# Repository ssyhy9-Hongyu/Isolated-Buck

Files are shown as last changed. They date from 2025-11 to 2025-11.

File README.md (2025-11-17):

# Isolated-Buck
50W Isolated Buck Converter (Two Switch Foward Converter) Project

Project Date: Sept.2022 - Jan.2023
Location: Nottingham UK  
People: Hongyu Yan, Pengyuan Shu, Jasleen Kaur, Jed Gawan

System block diagram:


Photo of the converter:


PCB Design Schematic (Converter Board):


PCB Design Schematic (Control Board):


PCB Layout (Converter Board):


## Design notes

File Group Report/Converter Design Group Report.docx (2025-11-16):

Converter Design Group Report

Introduction

The main aim for the project is to design a fully controlled two forward converters that outputs and regulated voltage. In Figure 1, we see a 230V, 50Hz AC supply, replicating a mains supply. This is stepped down to 30V, 50Hz using a XFMR gate drive transformer. This report covers the development of two main sections, the isolated two switch forward converter and the MOSFET gate drive.

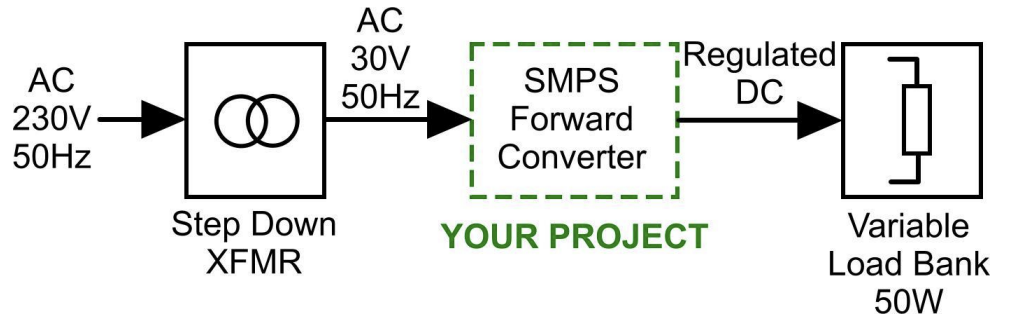
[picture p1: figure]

Figure 1. Project block diagram

The task is to produce a stable regulated output voltage across this load bank, regardless of the load. An isolated two switch forward converter is a type of converter that changes the AC input to a DC output. This converter can provide isolated output voltage. This would end up being connects to a 50W variable load bank.

The forward converter was designed and simulated under ideal and non-ideal conditions. Calculating the different components of the forward converter

Control circuits have low voltage and power levels, whilst power MOSFETs have high voltages and powers. Providing electrical isolation between these sections is mandatory to ensure safe and reliable operation. For this, the MOSFET Gate Drive circuit is responsible. Within this report, the operation of the gate drive is explored along with the purpose of each component. The need for coupling capacitors, Zener diodes and several resistors is investigated along with the effect of each component on the signal and the converter. The resultant output is then seen.

This report presents the design and simulation of a forward converter, under both ideal and non-ideal conditions. The initial calculations involved determining the necessary component values, duty cycle, and switching frequency, which in turn allowed for the calculation of important factors such as the turn ratio, output inductors, and capacitors. Non-ideal factors, including the capacitors' Equivalent Series Resistance (ESR), winding numbers, and equivalent resistance, were also taken into account. The simulations of the converter were carried out under ideal and non-ideal conditions, and the effect of an AC-derived input was also explored. The report then delves into the MOSFET Gate Drive circuit, which is crucial for providing electrical isolation between the control circuits (with low voltage and power levels) and the power MOSFETs (with high voltages and powers). The operation of the gate drive and the role of each component, such as coupling capacitors, Zener diodes, and resistors, are explored, along with their effects on the signal and the converter. The report concludes with the resultant output.

Calculations for the Forward Converter

Given values:

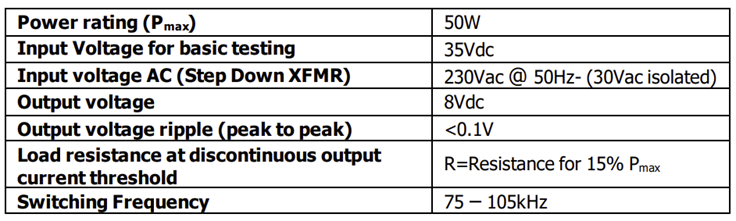
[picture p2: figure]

Duty cycle:

For the converter design, the duty cycle was limited to 50% to avoid saturation of the transformer core. Thus, initially, a duty cycle of 40% was chosen. However, a 30% duty cycle provides a higher range of the duty cycle to control the output voltage.

Turns ratio:

V_0 =((N_1)/(N_2))dV_s

(N_2)/(N_1)=(V_0)/(d∙V_s)=(8V)/(0.3∙35V)=16/21

Switching Frequency:

States anything between 75kHz and 105kHz. Decided on 100kHz.

Output filter inductor:

Use minimum load condition to get ΔI_L :

I_(RMS) =P/V=(50W×0.15)/(8V)=0.9375A

ΔI_L =I_(peak) =√3I_(RMS) =1.6238A

Voltage time area equation to find the inductance:

L=(VTA)/(ΔI_L)=(VTA)/(I_(peak))=(V_0 (1-d)∙T_(sw))/(I_(peak))=(8V∙0.7∙1/100kHz)/(1.6238A)=34.487μH

Output filter capacitor:

Use current time area equation to find the capacitance:

C_0 =(ITA)/(ΔV_0)=(I_(RMS) ∙(T_(sw))/2∙1/2)/(ΔV_0)=(0.9375A∙5μs∙0.5)/(0.1V)=23.4375μF

****************************

In terms of simulation with non-ideal components, the ESR (equivalent serial resistance) of capacitors, the DCR (DC resistance) of inductors, the resistance and forward bias voltage of diodes, the on-resistance of MOSFET, and the losses on the transformer should all be reflected on the schematic. Among all the component values, most could be found on the datasheet of their own, including the forward bias voltage of diodes, on-resistance of MOSFET etc. The following part of this section presents the methods to calculate or estimate the equivalent component values which could not be found on the datasheet directly.

Capacitor ESR Calculation:

The capacitor ESR is dependent to the capacitance and the power dissipation factor which could be found in the datasheet.

The primary part of the converter is operating around 35V and the voltage across output filter is around 10V. Therefore, the dissipation factor chosen for the corresponding capacitors are 0.12 and 0.2. The ESR could be calculated using the equation below:

ESR=tanσ∙ Xc=tanσ∙1/(2πfC)

The capacitors placed after the rectifier for smoothing the input voltage works at 100Hz while the capacitors at the output end of the converter are operating at 100kHz, the capacitances could hence be derived:

C_(output) =0.2×1/(2×π×100k×23.4375μ)=0.014Ω

C_(input) =0.12×1/(2×π×120×1000μ)=0.16Ω

Main Converter transformer winding number calculation

The number of turns on the transformer is determined by the equation below (the derivation steps are skipped):

N=(VTA)/(ΔBA_(core))

In this equation, the cross-section area of the core is settled (97.1 mm^2 ) and VTA is calculated in the worst case scenario, which refers 50% duty cycle. Although the flux density of N87 material saturates at around 500mT from the datasheet, the value of maximum flux density is chosen as 150mT to reduce the losses in the transformer and increase the efficiency. Therefore, the number of windings on the primary part of the transformer:

N=(0.5×35×1/(100k))/(150×10^(-3) ×97.1×10^(-6))=12

According to the primary and secondary turns ratio:

N_2 =N_1 ×16/21=10

The magnetising inductance of the transformer could hence be calculated using the number of turns by the equation below:

L_(mag) =A_L N^2

Where A_L =2600nH , N=12 :

L_(mag) =2600n×12^2 =374μH

The magnitude of magnetising current could be calculated based on L_(mag) to further validate of the choice of maximum flux density is reasonable or not. When the MOSFETs are at their ‘off state’, at the primary part of the converter, the magnetising current is flowing back to the power source:

I_(mag) =(VTA)/(L_(mag))=(70%×(-35)×1/(100k))/(374μ)=0.65A

It could be observed that the magnitude of the magnetising current is reasonable. Therefore, the numbers of turns on the transformer are settled as 12 turns and 10 turns.

Main Converter Transformer Winding Equivalent Resistance

The equivalent resistance of the windings is dependent on the length and the type of the copper wire which have been used to build the transformer. To choose the wire with correct diameter, the skin depth of the wire is found using the equation below:

δ=√(ρ/(πfμ_r μ_0))

The following parameters are fixed for copper material:

ρ=1.678×10^(-8) Ωm, f=100kHz, μ_r =0.99, μ_0 =4π×10^(-7)

Therefore, the skin depth is found to be 0.206mm at 100kHz for copper.

For the main converter transformer, any current density between 2-8A/mm^2 is considered reasonable and the current through the transformer is also dependent on the resistance of the load. Thus, for safety reason, the thickest wire (20AWG) is chosen which has an effective cross-sectional area of 0.39 mm^2 (after considering skin depth).

The equivalent resistance of the windings on the transformer could hence be calculated as the type of the wire and the number of turns has been chosen. The following calculations show the method to estimate the resistance:

R_(primary) =N_1 πD∙R_(wire) =0.015Ω

R_(secondary=) N_2 πD∙R_(wire) =0.012Ω

Winding Number of the Output Filter Inductor

As the inductance was calculated to be 34.57μH , the winding number of the inductor could be given as the following equation:

N=√((gL)/(μ_0 A_(core)))=√((0.5mm×34.57μH)/(4π×10^(-7) H∙m^(-1) ×97.1mm^2))=11.9

Thus, we pick N=12 as the winding number of inductor.

Inductor DC Resistance

The wire of 0.81mm diameter has been chosen for winding. The resistance of the winding could be given to be:

R_L =ρ_(cu) (L_(cu))/(A_(cu))=ρ_(cu) ×(2Nπr_(core))/(πr_(wire) ^2)=1.72×10^(-8) Ωm×(24∙5.56mm)/((0.405mm)^2)=0.014Ω

Simulations Results under ideal conditions

Simulation Settings

The simulation time was set to 0.005s and the max step size was set to 1×10^(-6) to ensure the accuracy of the simulation result. Two loads with different resistances were connected to a switch at the output end of the circuit. The step-input-driven switch would jump to the load with higher resistance from the load with lower resistance at 0.002s to simulate the change of load in real working conditions.

Results & Observations

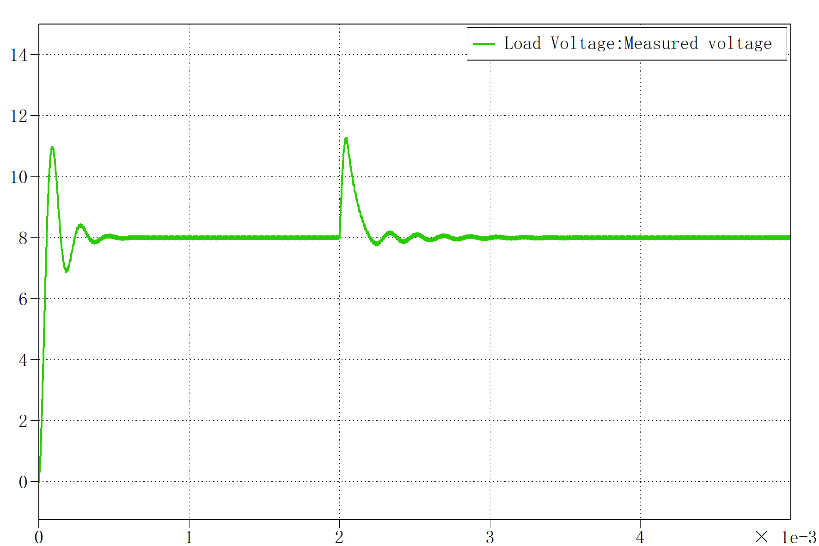
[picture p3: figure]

Figure 2. Simulation result of ideal conditions

It can be observed that there are generally two significant overshoots in the plot, where t=0s and t=2ms respectively. The output load is 2Ω initially, and has been changed to 8Ω after 2ms. It is apparent that the change of load causes the overshoot. Comparing these two overshoots, the first one takes less time than the second one to steady, this might because

Simulation results with non-ideal components

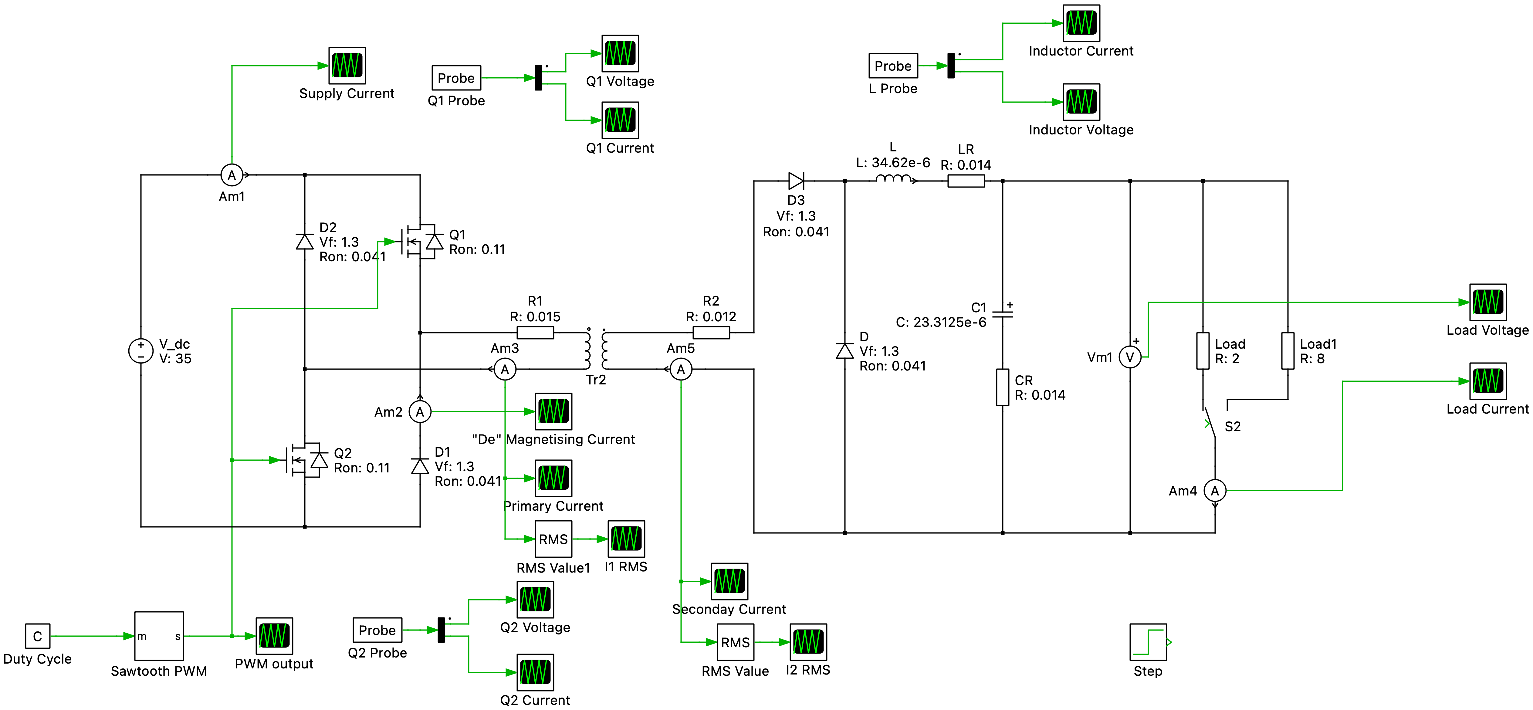
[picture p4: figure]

Figure1.1 Non-ideal Schematic With 35Vdc Input

Simulation Settings

The simulation settings of the non-ideal circuit were identical to the ideal circuit except the changes in component values as shown in the schematic above.

Results & Observations

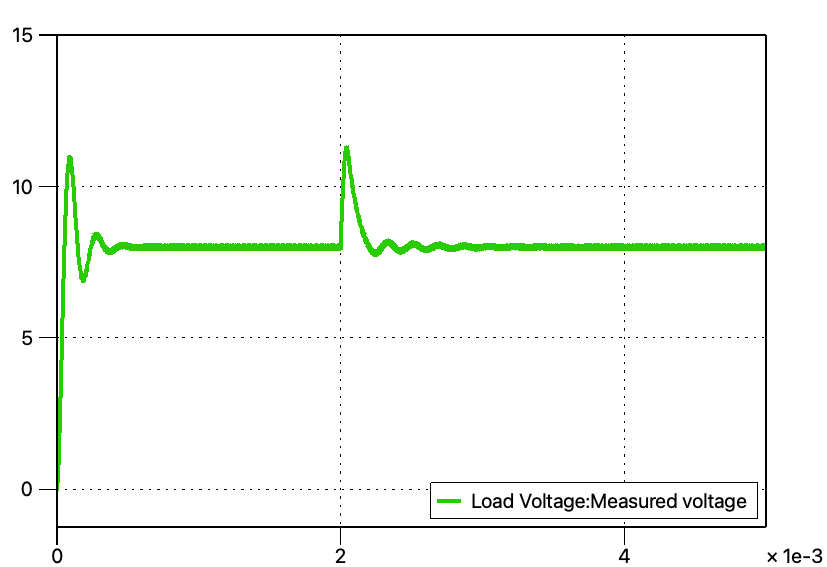
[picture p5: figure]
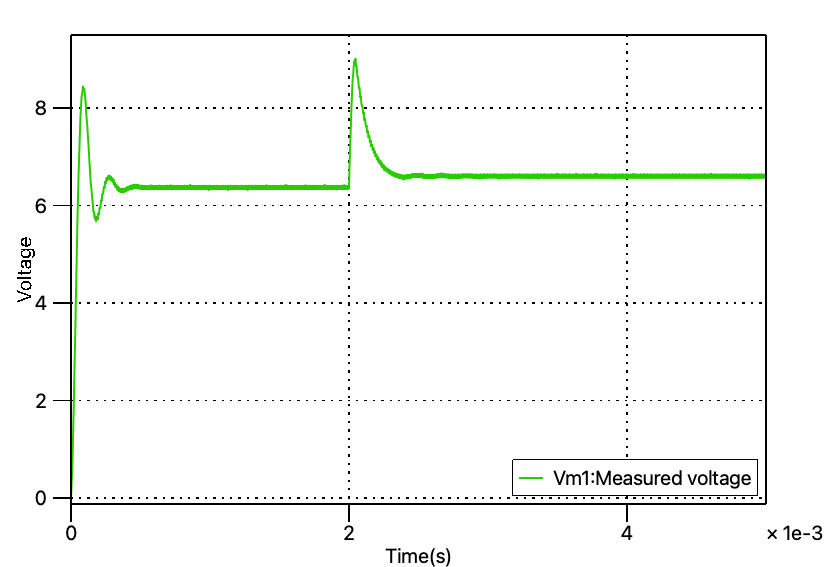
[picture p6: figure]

Figure1.2 Ideal(left) and Non-ideal(right) Output Voltage

Two major differences could be found by comparing the output voltage plot of ideal and non-ideal simulations. The first point is that the stable voltage on the load of non-ideal simulation is smaller than that of the ideal simulation. The second point is that in non-ideal simulation, the steady state voltage across a larger resistance load is higher than the voltage across a smaller resistance load.

The possible explanation to the first difference is that after taken the forward bias voltage on the diodes and the equivalent serial resistances into consideration, there would be voltage drops on every circuit component while the input voltage remains the same, which results in a relatively lower output voltage in the non-ideal simulation. In terms of the second difference, the changes in the voltage level are seemed caused by the difference in the load resistance, however, it is the difference in current which directly leads to the result. The larger load resistance would lead to a smaller current in both primary part and the secondary part of the converter. As the power rating of the converter and the turns ration on the transformer are consistent, the voltage drop across the components would hence be smaller when the current flowing in the circuit became smaller, thus, the steady state voltage across the load would be higher when a larger resistance load is applied to the circuit.

The peak to peak value of the ripples at the steady state voltage is around 0.08V, smaller than 0.1V that required by the customer. The ripples in the steady state voltage are mainly caused by the charging and de-charging process of the capacitor, therefore, the peak to peak value could be further reduced by using a capacitor with larger capacitance in the circuit. However, the feasibility of using a very large capacitor on the PCB is doubtful mainly due to the limited space on the board.

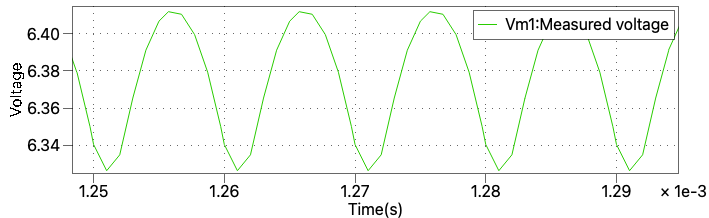
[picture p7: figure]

Figure1.3 Ripples at Steady State Voltage

Besides the observations on the output end of the converter, another simulation result that could guide the future practice is the current magnitude on the transformer. The RMS value of the current directly determines the heat losses of the converter while the current value has an inverse linear relationship with the load resistance, it is important to keep the current density on the wires at a safety region. In the case of copper wires, this figure should be around or below 5A per square millimeter according to the instructions while the thickest wire in the lab only has a cross sectional area of 0.39 mm^2 after considering the skin depth which has been calculated previously. The figures below are the RMS current values on the secondary winding under a small load(2 Ω ) and a large load(8 Ω ).

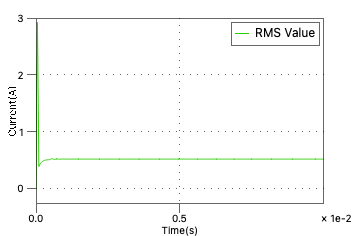
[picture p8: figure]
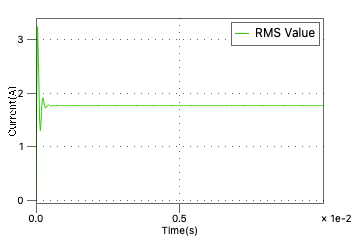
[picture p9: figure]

Figure1.4 RMS Current Value on Secondary Winding under 8 Ω (left) and 2 Ω (right) Load

The current value is roughly at 0.5A under big load and 1.8A under small load, which give an instructional idea on wire type selection in practice.

Simulation Results with AC derived input

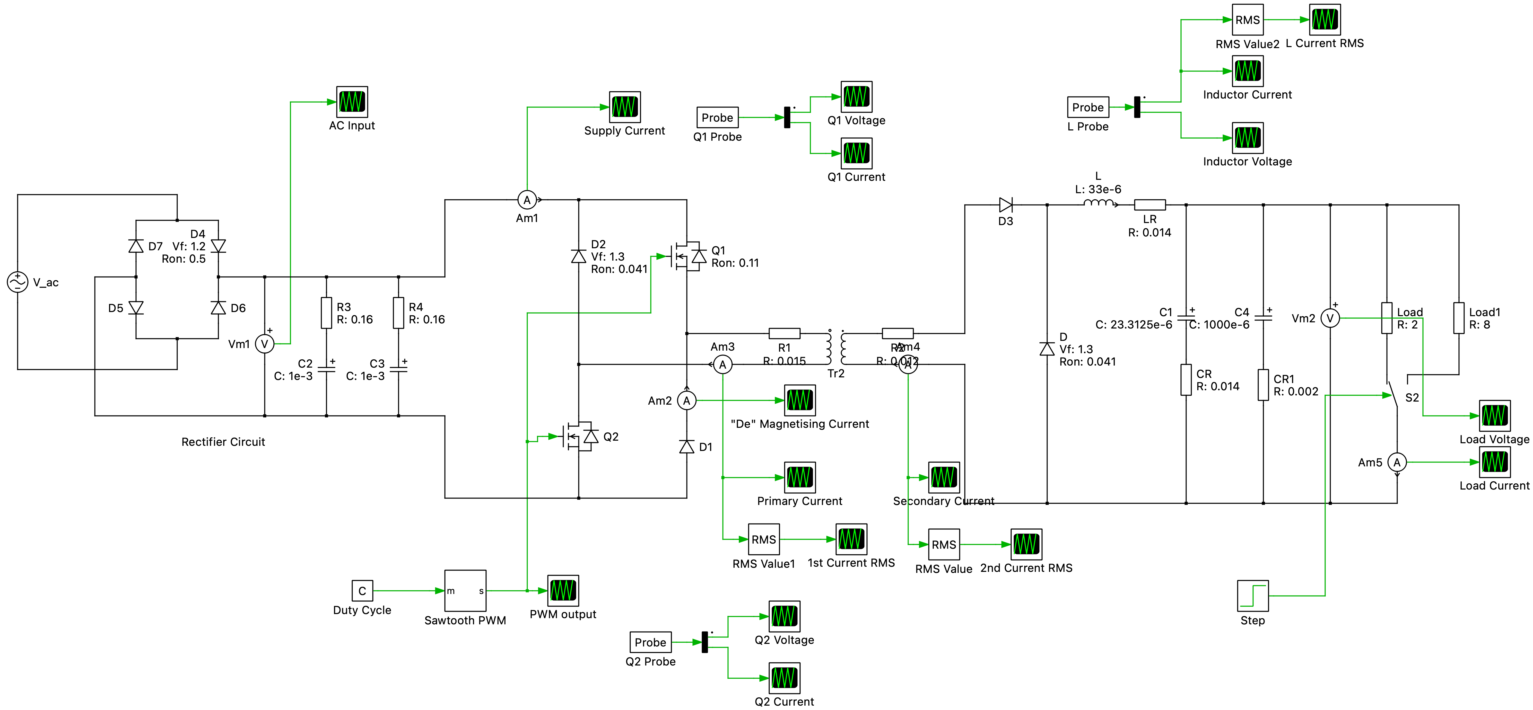
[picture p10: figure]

Figure2.1 Non-ideal Schematic with AC Input

Simulation Settings

The simulation time was increased to 0.2s to obtain the stable wave forms, the rest of settings were identical to the non-ideal circuit except the changes in circuit layout and component values as shown in the schematic above.

Results & Observations

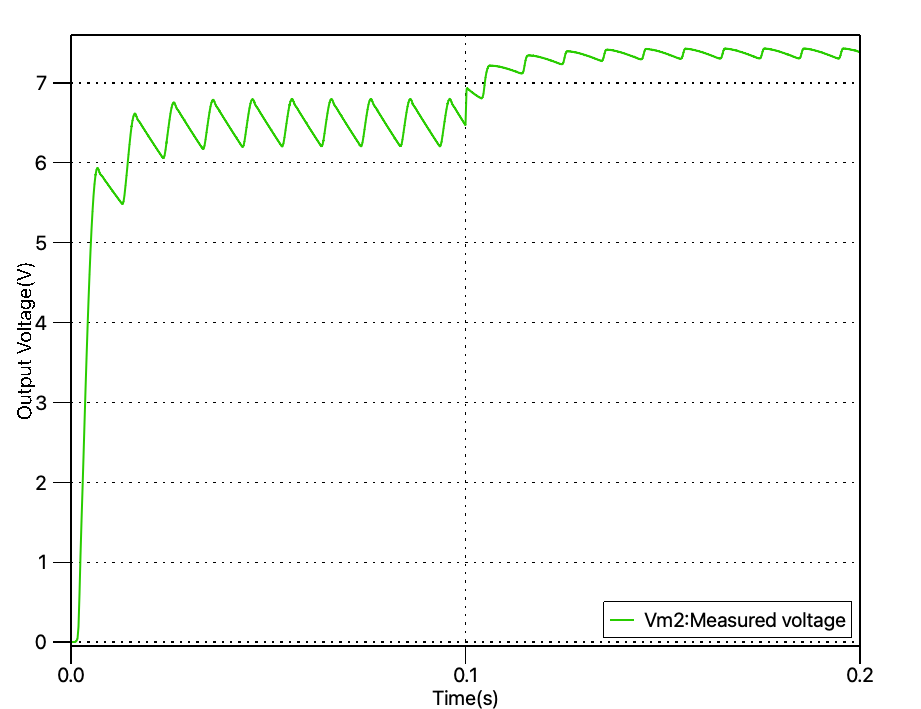
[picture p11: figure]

Figure3.1 Non-Ideal(left) and Non-Ideal with AC Input(right) Output Voltage

It is observed from the figure above that the ripples in the output voltage(not referring to the big ripples caused by the AC input) is around 0.005V, significant smaller than that in the non-ideal simulation. This change is due to a relatively large capacitor ‘CR1’added into the circuit. The capacitor

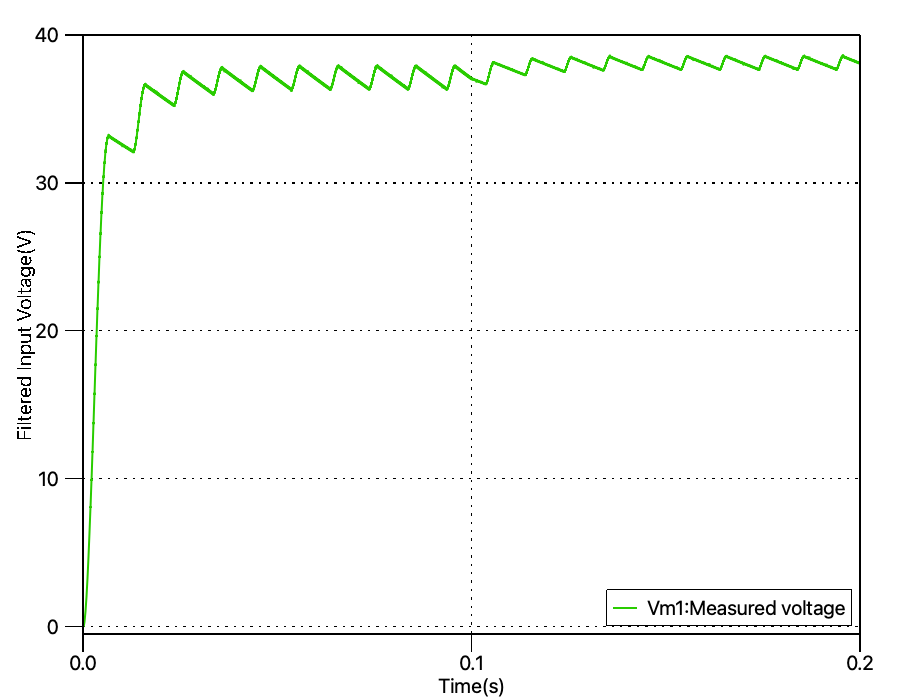
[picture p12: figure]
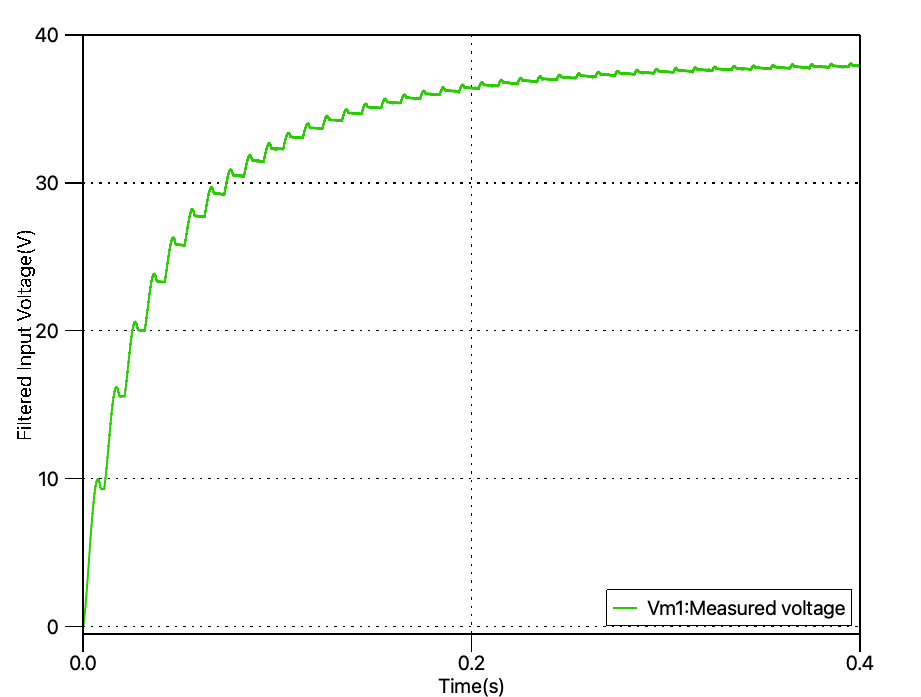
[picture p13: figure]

Figure3.2 Filter AC Input via 2uF Capacitor(left) and 20uF Capacitor(right)

Large Ripple

Small Ripple(why smaller, resistor impact)

Gate Drive Circuit

The gate driver circuit was implemented in order to provide electrical isolation between the control section of the converter and the high frequency power section. This isolation was necessary to provide safety between the high and low power components and to ensure reliable operation of the power electronics.

Figure X shows the schematic diagram of the gate driver circuit, with the MOSFETs represented as capacitors. The components within the gate driver circuit are carefully selected and arranged to enable efficient operation of the MOSFETs, which act as power switches in the converter.

In the following section, the operation of the gate driver circuit is explained in detail, with each component's purpose discussed. The selection and arrangement of components are critical for the proper functioning of the circuit, and a thorough understanding of the circuit operation is necessary for successful implementation.

Figure x: Schematic of the Gate Driver Circuit

In the gate driver circuit, the input signal was a square wave with a selected switching frequency of 100 kHz and a peak voltage of 15V. The MOSFETs, used as a power switch, required an input voltage between 12V and 15V, in accordance with its specifications. The input signal contained both AC and DC components, which necessitated the use of a coupling capacitor, C1, to block the DC components prevent the transformer from being saturated by it. If the capacitor was not used, there would be a duty cycle-dependent voltage across the transformer windings, which would cause signal distortion and potentially cause damage to the transformer. As a result of C1, a shift in the signal was caused with not peaks of approximately 10.5V and -4.5V. The capacitor value had to be kept relatively large to enable effective DC blocking and prevent signal distortion caused by the voltage drop at the capacitor.

The signal then enters a unity transformer, which provides galvanic isolation and protection between the control and power sections of the converter. The transformer in the gate drive circuit helps to ensure reliable and safe operation of high-power switching devices by allowing a safe signal transfer. To avoid time delays that can decrease system performance and reliability, such as increased power dissipation, reduced switching speed, and accuracy, a low leakage inductance is required for the transformer. Trifilar winding was used to reduce the leakage inductance. Trifilar winding involves winding wires closely together with the same number of turns, which reduced the amount of flux leakage between the windings, thus reducing the leakage inductance.

The role of the second coupling capacitor in the gate drive circuit was to restore the voltage drop within the signal, maintaining voltage levels of 15V and 0V. Meanwhile, the Zener diode functioned to clamp the voltage at a safe level, providing the MOSFET with protection from overloaded conditions. During turn-on and turn-off, the voltage levels could rise above the MOSFET's voltage rating of 20V, potentially damaging the device. However, this risk was mitigated through the use of a Zener diode with a breakdown voltage of 18V. Although the MOSFET had a maximum gate-source voltage of 20V, a voltage of 18V was used to provide an additional safety margin, especially since the MOSFET only required 12V-15V to operate.

The MOSFETs was represented with capacitors, C5 and C6, because the gate terminal of a MOSFET behaves like a capacitor, and it has to be charged and discharged through a resistor in order to turn the MOSFET on and off. The gate capacitance is typically much larger than other capacitances in the circuit, which is why it is represented separately as a capacitor. By representing the MOSFET as a capacitor, the simulation program can accurately model the charging and discharging of the gate capacitance and provide accurate results for the circuit's behaviour.

The gate resistor, RG, was responsible for charging and discharging the gate capacitance within the MOSFET which meant choosing a correct value for it was mandatory. Since, a small value of the gate resistor, caused the gate capacitor to charge faster increasing the turn on speed and thus decreasing the power losses. However, it can cause excessive current to flow into the gate at turn on, which can potentially damage the MOSFET. Thus, a suitable value limiting the current but providing a fast enough rise time was selected.

The gate source resistor, RGS, was a necessary component responsible for removing the charge stored by the parasitic capacitances, C5 and C6, between the gate and the source. Without this resistor, the MOSFET becomes unpredictable and may have floating voltages due to parasitic interference and noise. Since it was responsible for the removal of charge, its value was dependent on the time constant, which meant that a large RGS would increase the switching times leading to higher power dissipations and thus thermal losses.

From a selection of the correct components the following result was produced within figure x. It displays a peak at 14.3V and -0.7V approximately. With the voltage drops in the peaks caused by the Zener diode in forward mode.

Figure x: Output of the capacitors representing the MOSFETs

Conclusion

For gate drive: In conclusion, the gate driver circuit plays a critical role in the proper functioning of the MOSFETs. The circuit components were carefully selected and arranged to enable efficient operation of the MOSFETs. The use of coupling capacitors, a unity transformer, and Zener diodes provide reliable and safe operation of high-power switching devices, while the proper selection of gate resistors and gate-source resistors aids in reducing power losses, limiting current flow into the gate, and removing charge stored by the parasitic capacitance.

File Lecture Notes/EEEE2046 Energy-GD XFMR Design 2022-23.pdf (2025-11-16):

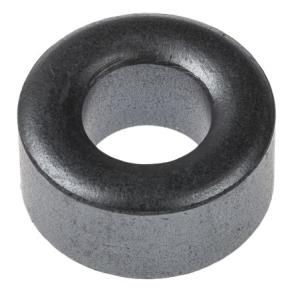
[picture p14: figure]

EE2046 Energy Project – Gate Drive Transformer Design

## Department of Electrical and Electronic Engineering

## EEEE2046 Energy: Things to consider for the Gate Drive Transformer 22-23

### 1.0 Introduction

This document provides some basic information which should be considered when designing and constructing the transformer for the MOSFET gate drives of the two transistor Forward Converter in EEEE2046 (Energy Project). It is not a complete guide for the design of the transformers but instead should be used as a reference for the most important considerations.

Figure 1: Toroidal magnetic core

The gate drive transformer should be small as it only transfers a few Watts of power from the supply to the MOSFETS. As a result a toroidal core is chosen.

### 2.0 Core material selection

Below are a few core materials (there are many others) which are used in magnetic components in power electronics applications.

Laminated Silicon Steel- Used in low frequency AC applications where a “Soft Iron” core would suffer from high Eddy current losses. Has a high saturation flux density 1.5-1.8T.

Ferrite- Generally used in high frequency applications. The ceramic nature of the material means that it is highly resistive to electrical current and therefore has very low eddy current losses and does not need to be laminated. The saturation flux densities are in the 0.4-0.5T region.

Powdered Iron- Not generally used for transformers because powdered material has an inherent “Distributed air gap” which lowers the permeability of the core. They have a saturation flux density of around 1-1.5T.

Amorphous metal- These materials are non-crystalline or “glassy”. They can be used to produce highly efficient transformers (with a high saturation flux density) but are generally more expensive than other materials. There are many types, but, for example, “Metglas” cores have a saturation flux density of 1-1.5T.

We are using Ferrite. Research these materials and make yourself comfortable with the justification of this choice of material.

What type of Ferrite? There are many “grades” of Ferrite which are optimised for certain frequency ranges, flux densities, losses etc. We will use Ferroxcube (manufacturer) 3C90 ferrite. This is driven by the operational frequency range and the availability in bulk for the project.

### 3.0 Core Dimensions Selection

Selection of the required core for a transformer is usually done one of two ways:

a. The power rating of the required transformer is used as a design input and the correctly sized core is chosen from charts in manufacturer’s datasheets.
b. The “Area Product” method is used- this considers the current density (i.e. the required cross sectional area of copper wire) and the required maximum operational flux density as constraints to decide how big the core needs to be. The closest core dimensions are used to select the appropriate core.

Two appropriately sized cores have been selected for you. They are both toroidal (very common when considering “small” magnetic components). Both cores are actually larger than an optimised design would consider but they were readily available in bulk from suppliers and are large enough to wind without needing magnifying equipment. The available choices are:

- TN 13/7.5/5
- TN 14/9/5

Both use 3C90 grade ferrite and the datasheets are available on Moodle.

### 4.0 Maximum Flux Density (Bmax)

Below is a typical BH curve for a typical grade of Ferrite (not 3C90). We need to ensure that our flux density does not saturate the core.

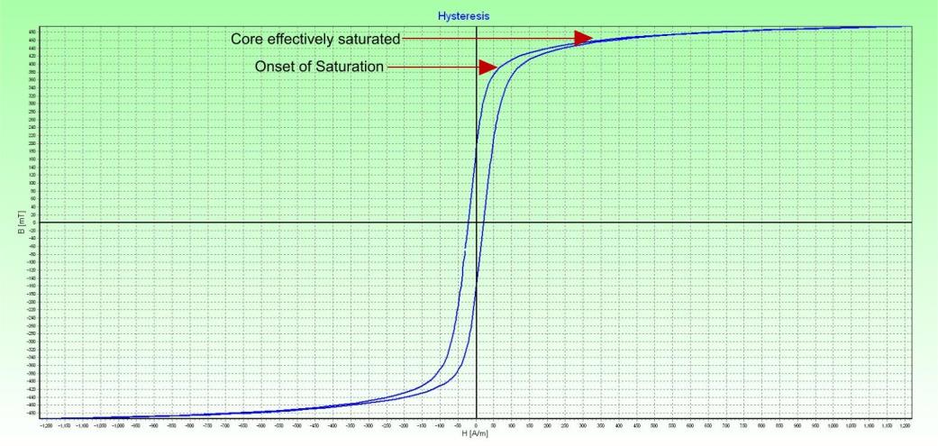
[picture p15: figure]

Figure 2: B (Flux Density), H (MMF) plot for a piece of Ferrite (Note: NOT 3C90)

Our peak operational flux density (Bmax) must be lower than Bsat for the 3C90 material. It should also be noted that the peak operational flux density will affect the Hysteresis loss of the core- i.e. the energy dissipated every time we “travel” around a loop (or cycle) of the BH loop.

You need to decide what Bmax will be for your 3C90 core.

### 5.0 Number of turns (N1, N2, N3)

The gate drive transformer has three windings and a 1:1:1 ratio. We only need to calculate the number of turns (N) for one winding- and then apply it to all three.

Starting from Faraday’s law:

V = N

dφ
dt

[1]

Where V is the voltage applied to the winding, N is the number of turns and φ is the flux created in the core. Rearranging this into the integral form gives:

1
N
∫V dt = φ1 − φ0 | [2]

Which can be converted to flux density (B) by considering that B/Acore= φ:

VTA

NAcore

= B1 − B0 = ∆B | [3]

Where VTA is the “Voltage Time Area” (See Power Electronics analysis in EEEE2045), and Acore is the cross-sectional area of the core. Finally, ΔB is the change in flux density.

This can clearly be re-arranged and re-labelled to calculate the number of turns required for a winding:

VTA

∆BAcore

= N | [4]

You need to decide what the “Worst case” VTA that will be applied to the core- this will give the largest shift in flux density. ΔB= Bmax i.e. the highest VTA must keep the flux density below the Bmax chosen in the previous section. Clearly the calculated N must be a whole number.

Once N has been calculated, the number of turns for each winding is N1=N2=N3=N.

### 6.0 Magnetising Inductance (Lmag)

Calculation of the magnetising inductance of the transformer can be used to help deduce the magnetising current value which in turn is useful for calculating the required wire size. The inductance of the core can be calculated two main ways.

a. The first method considers the reluctance of the magnetic core and uses this and the number of turns to calculate the inductance from:

Lmag =

N²

ℜ

[5]

Where Â is the reluctance of the core which can be calculated using:

ℜ =

1

Acore

[

lcore
μrμ0
] | [6]

Where µr and µ0 are the relative permeability and the permeability of free space (4π x10⁻⁷Hm⁻¹ )
respectively.
b. The alternative method for calculating the magnetising inductance is to use the AL value given in the datasheet for the core (you must make sure that it considers the right grade of core material). AL (in nH) is the inductance per turn squared. As such it is possible to calculate the magnetising inductance of the core from:

Lmag = ALN²
| [7]

### 7.0 Size of wire (Cross Sectional Area, Acu)

Now we know how many turns that each winding of the transformer will have we need to determine the size of the wire. There are two main constraints

a. The RMS current density in the wire must be below around 3A/mm²
. This will ensure that the winding does not get too hot during operation- the worst case being that the insulation melts off the wires and all of the turns on the winding short circuit.

The current density is unfortunately not straight forward. At high frequencies the current is concentrated in an outer “skin” on the conductor and as a result the current density is increased. You need to determine the “skin depth” and calculate the current density from this. The required information is readily available on the internet and in books [1].

Figure 3: “Skin Effect” and its impact on current density of a circular conductor

b. The three windings clearly need to fit on the core. The available “window” for the winding can be calculated for the core (it’s the area in the middle of the toroid where we will put the winding). However, we also consider a “Fill Factor”, Kfill, as a result of the fact that it is impossible to fill the winding area in a practical magnetic component. For a toroid, the fill factor is between Kfill=0.2 and Kfill=0.4. Clearly:
KfillAwindow > 3NAcu | [8]

Note: You must also consider that only certain sizes of wire are available in the lab and this adds a further constraint. These sizes are given in AWG (American Wire Gauge) -tables converting this to mm² are readily available online.

### 8.0 Losses

As for any wound magnetic component there are two main sources of loss. The first is the core loss. For Ferrite, Eddy currents can be neglected because the material is a good electrical insulator. Hysteresis loss can be considered using manufacturer datasheets or design software. For the gate drive transformer, the worst case VTA will determine the highest hysteresis loss (you need to think about why this is the case). The second source of loss is in the resistance of the windings of the transformer. The DC resistance of the wire can be calculated using the resistivity of copper (ρcu) and the dimensions of the wire, similarly to the forward converter output inductor [2]:

RDC = ρculcu/Acu | [9]

Nearly all the
current flows in
this part

Hardly any current
flows in this part

Skin depth δ

The AC resistance is more challenging to calculate as a result of the complication caused by the “Skin Effect” at high frequencies. Whether this needs to be considered or not depends on the size of the wire chosen for the gate drive transformer. Further information is available in [1].

### 9.0 Winding Techniques

We now have wire and the required number of turns for each winding. We need to think about how we are actually going to put the windings on core. There are three main options

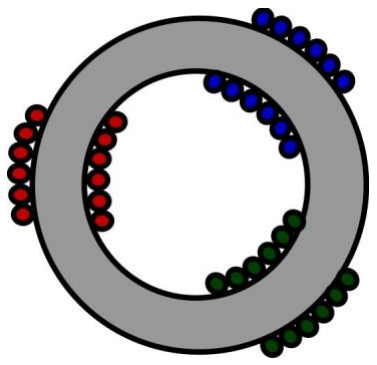
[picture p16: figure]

Figure 4a: Option 1: Put
each winding separately
spaced around the core

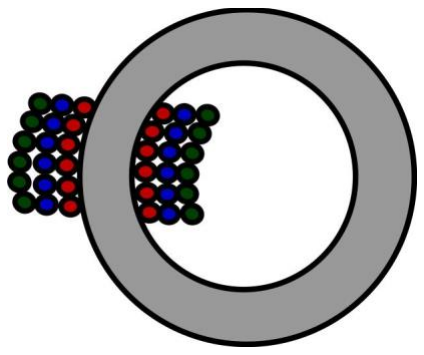
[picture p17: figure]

Figure 4b: Option 2: Put each winding on top of each other (note: turns could be
distributed further around the transformer)

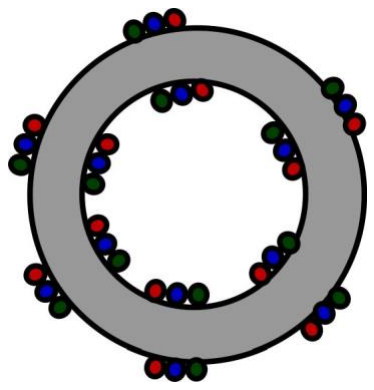
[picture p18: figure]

Figure 4c: Option 3: “Trifilar” wind the three windings
together, next to each other at the same time

The choice of winding method is determined by consideration of two main points. The first is the insulation requirements i.e. do we need to separate the windings using insulating materials (note that the wires are already coated in a thin film of enamel- enough to prevent “turn to turn” short circuits). The second is the effect of the winding method on the circuit. For the latter, in particularly the winding method has an impact on the Leakage Inductance (see first year notes for Power and Energy) of the circuit- a winding method should be selected to minimise this. At high frequencies, the capacitance of the windings (remember that windings are two conductors separated by a dielectric insulator) can also create issues but this will not be considered in this project.

References
[1] Ron Lenk, "Practical Design of Magnetics," in Practical Design of Power Supplies , 1, Wiley-IEEE Press, 2005, pp.288- Available on campus on IEEEXplore
[2] Jon Clare, “EEEE2046 Energy Project: Designing an Inductor”, November 2017, Available on Moodle.

Further Reading

[1] L. Warnes, “Electronic and Electrical Engineering Principles and Practice”, 3rd Edition, Palgrave Macmillan, 2003
[2] P.T. Krein, “Elements of Power Electronics”, Oxford University Press, 1998
[3] A. Van den Bossche, V. Valchev, “Inductors and Transformers for Power Electronics”, CRC Press, 2005
[4] W.G. Hurley, W.H. Wölfle, “Transformers and Inductors for Power Electronics”, Wiley, 2014
[5] https://kitsandparts.com/howtowindtoroidswithoutpain.php - a good source of information on how to wind a toroid.

Updated February 2023: Al Watson

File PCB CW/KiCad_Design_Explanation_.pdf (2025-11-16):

KiCad Design Explanation | 1

# KiCad Design Explanation

### Track width and thickness:

Main converter circuit:

The table below shows the design requirements of the main converter:

Vin | Vout | P
35V | 8V | 50W

The average current in the primary part and second part could be derived using the formula: I=P/V

Hence the estimated average current flowing in the main converter is listed in the table below:

Iin | Iout
1.43A | 6.35A

In the PCS design, considering the power losses across the components, the input power would be roughly 20% higher than the output power, the primary part track is hence designed to have the capability to deliver 2A current. The secondary part track is designed to have a 7A current tolerance. Therefore, the designed track parameters:

| Primary | Secondary
Width(mm) | 0.78 | 4.39
Thickness(mm) | 0.035 | 0.035

Gate driver circuit:

There are three factors affecting the choice of track width. Firstly, the peak output current from the MOSFET gate driver(4.5A). Secondly, the secondary and the tertiary windings are connected to PWM_COM_A and PWM_COM_B nets, which deliver a 2A current. Thirdly, the gate driver circuit is a high-frequency circuit, which would be very demanding on the low inductance of the tracks.

From the inductance calculation formula, the length of the track has the greatest impact on the inductance, followed by track width. Therefore, the gate driver circuit footprints are arranged compactly and the width of the tracks are set to 4.5mm.

### Capacitor Location

U39>>bypass capacitor(the smaller capacitance one), placed close to voltage source, to eliminate high frequency noise from the voltage source.

U37>>decoupling capacitor(the larger capacitance one), placed close to IC circuit, to reduce the impact of the varying voltage levels on the IC circuit. A relatively larger capacitance is chosen because it is the energy-storing feature that we need.

### General Considerations:

45-degree corner: every corner in this design is 45-degree, to reduce the possibility of radiated Electromagnetic Interference (EMI), which has a great impact on high frequency circuits.

Input ports are placed on the left side of the board, output ports are placed on the right side of the board for convenience.

There is a reasonable clearance(distance) between the power converter circuit and the control circuit, to reduce possible interference.

All GND pins are connected to a filled zone at the back of board to reduce electrical noise and interference through ground loops.

### Thermal Management

Heatsinks are attached on two MOSFETs and two diodes on the converter output end, where large current flows.

Multiple thermal vias are placed under the 4-diode-rectifier and the MOSFET Driver to increase heat convection.

### Testpoints:

Unit Reference | Testing Property
U1(TP1) | Rectifier PWM output
U3(TP2) | MOSFET1 Vgs
U7(TP3) | MOSFET2 Vgs
U9(TP4) | Converter primary current
U10(TP5) | Converter transformer output current

### Warnings Explanation

KiCad Design Explanation | 2

‘Silkscreen clipped by solder mask’: Caused by silkscreen layer overlap with solder pad, has no impact on the function of the circuit, could be

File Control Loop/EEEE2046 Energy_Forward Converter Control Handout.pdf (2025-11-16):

EEEE2046 Electrical Project – Control Design and Control System Modelling | 1

## Department of Electrical and Electronic Engineering

## EEEE2046 Electrical Project

### Control System Design and Control System Modelling

## 1 Introduction

In the EEEE2046 “energy” project, you should design and implement closed loop control for your power supply. The control is needed to achieve two main aims:

- Steady state accuracy of the output voltage (for example when the load resistance is changed).
- Stopping (most of) the 100Hz ripple created by the rectifier from appearing at the power supply output.

In achieving these aims it is also a requirement that the control loop has good stability and transient response. Some of these ideas were discussed in the “Introduction to control lecture” – slides for that are on Moodle.

To do a control design (of anything) there are basically two tasks:

a) System modelling – to get a mathematical model of the system than can be used to do the control design.
b) Controller design - determining what type of controller to use and designing its parameters based on the mathematical model of the system and the control requirements.

For power electronic systems, (a) can be quite challenging because of the nature of the system (changing circuit topology when the switches operate, non-linearities etc) whilst there are often standard approaches that can guide us in (b). Fortunately, the Forward Converter is one of the easiest converters to model and control – one of the main reasons why we chose it for this project instead of something else (the Flyback converter for example).

This handout guides you through the process of designing and implementing a closed loop controller for your converter.

There are a number of appendices. Appendix A deals with the system modelling – its purpose is to provide the models needed to do the controller design. There will be some ideas here that are new to you (and are studied in more depth in years 3/4) – you should be able to understand most if not all of it – but if you find it difficult it is not essential to follow absolutely everything there – you really just need the models to do the design (which you do need to understand fully).

Appendix B deals with transfer function calculation – firstly for the output filter and secondly for calculating the parameters of the amplifier circuit to implement a particular controller design transfer function. Again – the results here are what you need to do the design – but you should be able to follow where they come from.

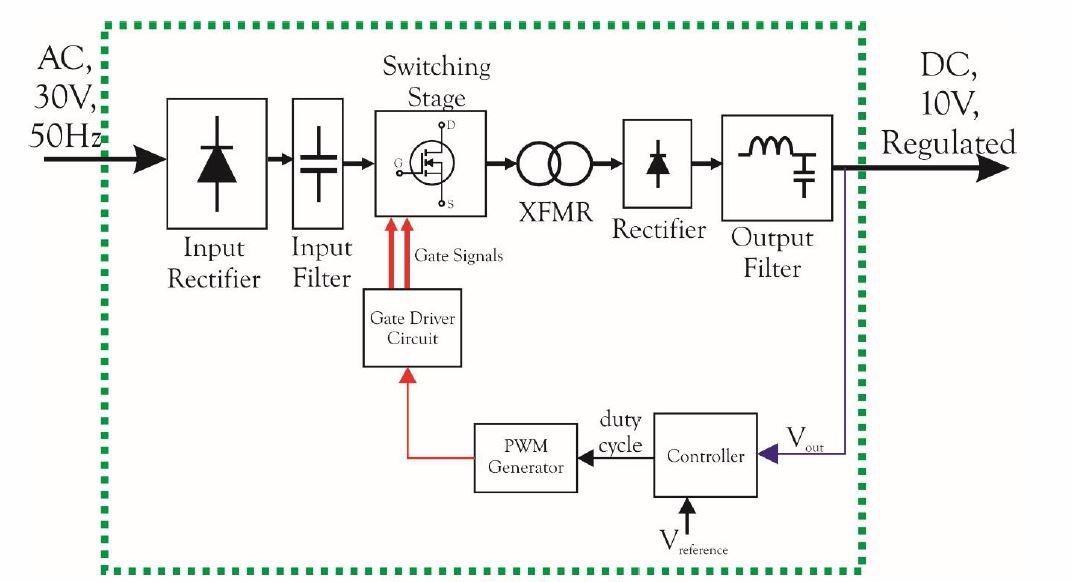
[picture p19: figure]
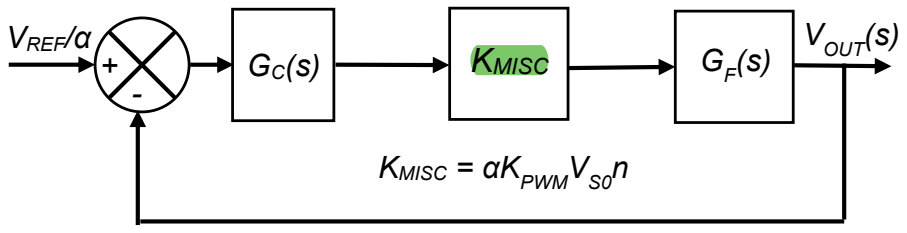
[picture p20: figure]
VREF/α; KMISC = αKPWMVS0n; VOUT(s) KMISC

EEEE2046 Electrical Project – Control Design and Control System Modelling | 2

The main part of the handout deals with the controller design. This builds directly on ideas that you will have met in the control part of EEEE2045 and you will need to study it and understand it well to design a satisfactory controller.

## 2 Control Design

### 2.1 Initial Considerations

A reminder of the overall system from the main project handout

Fig 1 Overall SMPS system
To do the control design – we need to get a mathematical model of this system in a block diagram form that we can use with standard control design methods. That is not particularly easy – all the detail is given in Appendix A – but the resulting model, shown in Figure 2 is fortunately quite simple (it is a unity gain feedback system of the type you will have looked at in EEEE2045).

In this model, GF(s) is the transfer function of the output filter, KMISC is just a gain that includes a number of things (transformer turns ratio, PWM chip etc – see Appendix A) and GC(s) is the transfer function of the controller.

Appendices A and B are quite detailed – the key concepts and results that you will need to do your control design are highlighted in boxes

Figure 2 Block Diagram Model for Controller Design

EEEE2046 Electrical Project – Control Design and Control System Modelling | 3

To do the control design we are going to use the Bode approach (because you have looked at it in EEEE2045 and it is a method that is frequently used in industry for this sort of design). Firstly, let’s have a reminder of some things you have seen before – which we are going to use and which you will need to be very familiar with.

### 2.2 A Reminder about Bode, Transfer Functions and Block Diagrams

Here are a few definitions and mathematical operations we are going to need to use.
“Loop Gain” – the gain of all the blocks in the loop multiplied together. In the system of Fig 2 that we will consider, this is given by: loop gain = KMISCGC(s)GF(s).
“Crossover Frequency (ωC) – this is the frequency at which the magnitude of the loop gain is unity (i.e = 1).
“Phase Margin” – this is the difference between -180O and the phase shift of the loop gain at the crossover frequency.
“Gain Margin” – this is (1 – magnitude of loop gain) at the frequency where the loop phase shift is 180O (it is the difference between the gain we have and the gain that would make the system unstable).
In order to use these definitions, we will need to calculate the gain magnitude and phase shift of blocks, defined as a Laplace transfer functions, at particular frequencies. Remember that to do this we simply replace s by jω and then calculate the modulus (= gain magnitude) and angle (= phase shift) of the resulting complex number.
MATLAB provides a number of tools for manipulating transfer functions and for evaluating gain, phase and drawing Bode plots etc which will be useful – see Appendix C.

### 2.3 Controller Design – Venable Approach

The two main tasks in controller design are:
a) Deciding what the controller transfer function GC(s) should look like (how many poles and zeros etc).
b) Working out the parameters of the chosen transfer function to get the desired control performance.
For complicated control problems, (a) can be quite difficult and often a lot of experience is needed – we are lucky however as plenty of people have looked at the same problem before and there are well documented approaches we can use. To do (b), there are standard methods – the Bode approach is one of them.
For this project, we are going to use an approach for (a) based on a classic paper by “H Dean Venable”:
Venable, H. Dean. “The K Factor: A New Mathematical Tool for Stability Analysis and Synthesis.” Proc. Powercon 10. 1983. San Diego, CA. pp. H1−1 to H1−12
Venable’s original paper is provided on Moodle for interest and reference – read it if you like but beware that some of his terminology and definitions are a little unusual and are potentially confusing. Everything you need to know about the method to do the design is in this handout.

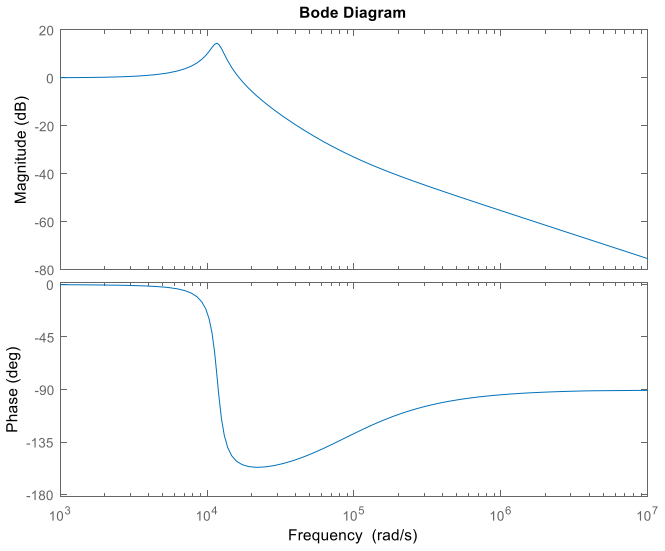
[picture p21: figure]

EEEE2046 Electrical Project – Control Design and Control System Modelling | 4

Venable defines 3 alternative transfer functions for GC(s) (Type 1, Type 2, Type 3) of increasing complexity and provides the method for designing them to get adequate stability (phase margin). The 3 alternatives are discussed below – for your design it is probably a good idea to do a Type 1 design first to get something working – then, if needed and you have time, you can try and improve it using one of the other types. The method is explained below, and then a step by step procedure is given.
2.3.1 A Simple Controller (Type 1)

The transfer function for the Type 1 controller is a simple integrator. Remember that we want a very small steady state error – so we need an integrator in the controller (see EEEE2045 notes).

There is only one quantity to choose here (A) so the design is quite simple. It is useful to define the gain of GC(s) at the crossover frequency:

G = |GC(s)|ωc = |GC(jωC)| = | A
jωC

| = A
ωC

(1)

Note that the phase shift of GC is always 90O (lagging) at all frequencies.

Following the Bode method we need to decide where to put the crossover frequency (ωC) and then we need to work out A and check the phase and gain margins (to see how stable the system is). Firstly, we need to consider the Bode plot of the filter transfer function GF(s) (see Appendix B.1 for the transfer function derivation). This will look something like below (note – this is just an example for some specific parameters I made up – yours will be different – you will need to calculate it – you can’t use this one!):

Figure 3 – Typical Bode plot for filter transfer function (GF)

GC(s) = A
s

EEEE2046 Electrical Project – Control Design and Control System Modelling | 5

Some things to note about the filter characteristic:
- The magnitude response at low frequencies is 0dB (i.e unity) – low frequencies pass straight through the filter
- It has a peak in the magnitude response at the resonant frequency (about 1.9kHz, 12krad/s in this case – yours will be different!)
- After the peak, the magnitude reduces with frequency – this is why it filters the switching frequency components
- The phase shift at the resonant frequency is 90O (lagging)
- The phase shift approaches 180O (lagging) – as we expect from an LC filter – but then reduces back to 90O at high frequencies. This is due to the zero created by the capacitor ESR.
We can immediately see that we have a problem here for this simple controller. There is a peak in the magnitude response at the filter resonant frequency and also, at this frequency, the loop phase shift will be 180O (90O from the integrator and 90O from the filter) – the loop gain must be significantly less than unity at this frequency, or we will have no gain margin.
From above, it should be clear that the crossover frequency must be significantly less than the resonant frequency of the filter to get a system with reasonable stability (with this type of controller). There is no definitive approach to selecting ωC however, and the “best” choice of ωC (and hence A) will depend on your filter characteristic and what gain/phase margin you need.
I suggest that you start by setting the crossover frequency at 1/10 of the filter resonant frequency – this should give a “safe” design and one that you can get working in the lab.
There is a little extra complication because the gain KMISC (see Fig 2) depends on the input voltage and the transfer function of the filter GF(s) depends on the load resistance – both of which are variable. To get around this, we have to decide what the “worst case” conditions are (the ones that will give minimum phase margin) and design for those conditions (this is very common approach). If we do that, the controller will work at all other conditions – the performance might not be as good – but it is the best we can do with a controller with fixed parameters. We can see (Appendix A.5) that the gain KMISC is directly proportional to the input voltage (VS0) and we should realise that higher gains will reduce the phase and gain margin – so we should design for the maximum input voltage. Also, we can see from the transfer function GF(s) that the peak in the magnitude response and the phase shift will be increased for larger values of load resistance R – both of which will decrease the gain and phase margin – so we should design using the minimum load condition (maximum load resistance). This is maybe not so obvious, but you will be able to prove it to yourself with 5 minutes of effort using MATLAB and plotting the Bode plot for your filter for different values of load resistance.
So, step by step, the suggested design procedure for Type 1 becomes:
[1] Work out the resonant frequency of your filter and set the crossover frequency to 1/10 of this – i.e
ωC = | 1
10√LC | (2)
[2] Work out the filter transfer function GF(s) for your filter (see Appendix B.1) using the maximum value of load resistance (corresponding to 25% load – see project specification).

EEEE2046 Electrical Project – Control Design and Control System Modelling | 6
[3] Work out the magnitude of the filter response at ωc (it should be pretty close to unity). Use MATLAB for this – see Appendix C – it will save a lot of time if you need to do it more than once!
[4] Calculate the value of KMISC – using the maximum expected value of input voltage (it is not critical to get a very accurate value – you can just use your simulation to get a sensible value). See Appendix A.5 for the derivation of KMISC – you will also need to know (or have decided) what potential divider ratio you are using on the output voltage (see Appendix A.3).
[5] Work out the required value of G (the magnitude of GC at ωc) to get unity loop gain at ωc. This is given by:
G = | 1
KMISC|GF(jωC)| | (3)
[6] Work out the value of A from: A = GωC (this step might seem a bit strange - why did we not just calculate A directly in step [4]? – this will become apparent if you do one of the more complex designs).
[7] Use MATLAB to check your gain and phase margins (see Appendix C). The phase margin should be fine (> 60 degrees) but you may find the gain margin is not i.e. the system will be close to instability. If it isn’t, you will need to reduce ωc and go back to [1].
[8] From the value of A, work out the values of R1 and C1 for the controller amplifier – see Appendix B.2.1.
Now you can try your controller in your PLECS model – it should work (PLECS has simple op-amp models and you will need to work out how to model the PWM chip). Try it with a DC input with different loads and with an AC input. Look to see if you meet the output ripple specification at 100Hz (< 0.2V) when you use an AC input – probably you won’t. You can then probably decide whether to try the simple controller in hardware – or try a more complex design (below) in PLECS – or to work on both at the same time.
2.3.2 A Better Controller (Type 2 or Type 3)

If you design a Type 1 controller it should work fine in keeping the output voltage stable when you change the load and it should work fine if you have a DC input (from a power supply). However, if you feed your circuit from the AC input via rectifier, it will almost certainly not meet the output ripple specification at 100Hz. Remember that the output filter is totally ineffective at 100Hz – it passes straight through, so we are relying on the closed loop control to remove the 100Hz ripple. In Appendix A.6 it is shown that:

Output ripple % at 100Hz = Input ripple at 100Hz/(1 + loop gain at 100Hz) Your input ripple will be something like 10% to 20% and the output specification is 2% - so you are going to need a loop gain of something like10 or better at 100Hz to meet that.
The Type 1 controller cannot provide this – using the method in 2.2.1, the crossover frequency will be a few hundred Hz probably (depending on your filter parameters) and that is where the loop gain is unity. You can try increasing the crossover frequency, but you will not (probably) be able to make it high enough to reduce the 100Hz ripple within the specification before is becomes very oscillatory, or unstable.
The solution is to use a more complicated controller either Type 2 or Type 3. If you have time to consider a better controller, I suggest you try Type 3 – with which you can definitely meet the

EEEE2046 Electrical Project – Control Design and Control System Modelling | 7

specification. The procedure for Type 3 is given below (if you want to try Type 2, then you can probably work it out by looking at this and looking at Venable’s original paper – and using the information in Appendix B.2.2).
The transfer function of the Type 3 controller is:

GC(s) = A
s

(1 + s ωC/√k

)

2

(1 + s
| √kωc

)

2

where k is Venable’s k-factor (defined later).

The integrator is still there as we need that for steady state accuracy. In addition, there are two zeros at a frequency below the crossover frequency and two poles at a frequency above the crossover frequency. The effect of the zeros is to provide a phase-lead, which reduces the overall phase lag of the control loop at the crossover frequency – “fighting against” the phase lag of the output filter. The two poles have to be there, as we can never realise a transfer function with more zeros than poles – the poles give a phase lag again, but they are above the crossover frequency to minimise the effect on stability. That is a very short discussion – you can look at Venable’s paper for more information – but this is pretty difficult stuff for Year 2 - so we will just concentrate now on how to implement Venable’s design.

We need to choose ωc, then we can follow Venable’s method to find k and G (and hence A). Then we can work out the component values for the amplifier.

So, step by step, the suggested design procedure for Type 3 is:

[1] Choose a value for ωC – with the Type 3 controller, we can put this above the filter resonant frequency – and again there is no exactly correct value. If you make it too low you won’t get enough loop gain at 100Hz – if you make it too high, then you risk instability due to switching frequency noise affecting the control loop (discussion of that is way beyond the expectation of Year 2 level – so we won’t discuss further). Probably putting ωC at twice the resonant frequency will not give the performance you want and 10 times will probably lead you into trouble – so pick something in between (the design can be iterated – it is normal to do that).
[2] Work out the filter transfer function GF(s) for your filter (see Appendix B.1) using the maximum value of load resistance (corresponding to 25% load – see project specification).
[3] Work out the magnitude and phase of the of the filter response at ωc. Use MATLAB for this – see Appendix C – it will save a lot of time if you need to do it more than once!
[4] Work out how much phase “boost” (B) you need at the crossover frequency to get a phase margin of 60O (this is a standard design value that is often used in Bode design)

Pℎase Margin (PM) = 180 − 90 + ∠GF(jωC) + B

B = PM − 180 + 90 − ∠GF(jωC)
Note that in this calculation, the phase angle of GF(jωC) will be negative (and remember to use degrees throughout!). You should come out with a value of B > 70O (if it is more than

EEEE2046 Electrical Project – Control Design and Control System Modelling | 8

150O – you have trouble – ask for help!). The 90O term in the equations above is due to the integrator.
[5] Venable gives a formula for calculating his k-factor in terms of the “boost” B (if you fancy a bit of a challenge – you can have a go at deriving it)

√k = tan[B

4⁄ + 45] → k = {tan[B
4⁄ + 45]}

2

[6] Calculate the value of KMISC – using the maximum expected value of input voltage (it is not critical to get a very accurate value – you can just use your simulation to get a sensible value). See Appendix A.5 for the derivation of KMISC – you will also need to know (or have decided) what potential divider ratio you are using on the output voltage (see Appendix A.3).
[7] Now we calculate the required gain of the controller (G) at the crossover frequency:
G = | 1 KMISC|GF(jωC)|
[8] Work out the value of A from: A = GωC/k (this is derived in Appendix B.2.3).
[9] Now you have all the transfer functions. Use MATLAB to check your gain and phase margins (see Appendix C). See if you have enough loop gain at 100Hz – if not try increasing ωc and go back to [1] (for this reason, it is a good idea to put the design process into a spreadsheet (or a MATLAB script) – so you can change it easily).
[10] Now you have G, ωC and k – that allows all the component values and (A) to be calculated using the results in Appendix B.2.3.

Now you can try the controller in your PLECS model – it should work. If it does, then you can try it on your hardware – it should work there as well – try it with a DC input with different loads and with an AC input. Look to see if you meet the output ripple specification at 100Hz (< 0.2V) when you use an AC input – with a Type 3 controller you should be able to.

## Appendix A - System Modelling

To do control design, the things we need to model in the system are:

a) The power circuit – and in particular how the duty cycle affects the output voltage and how the ripple coming from the rectifier affects the output voltage.
b) The PWM control chip – and in particular the relationship between the duty cycle demand and the duty cycle of the pulses that are produced.
c) The amplifier circuit that we are going to use to implement the controller – and in particular how its transfer function is related to the component values.

You may think that we did at least part of (a) in EEEE2045 where we derived an expression that related the output voltage to the input voltage and the duty cycle – BUT – that was for steady state operation – now we need a model that works for transient conditions when the duty cycle and input voltage are not constant.

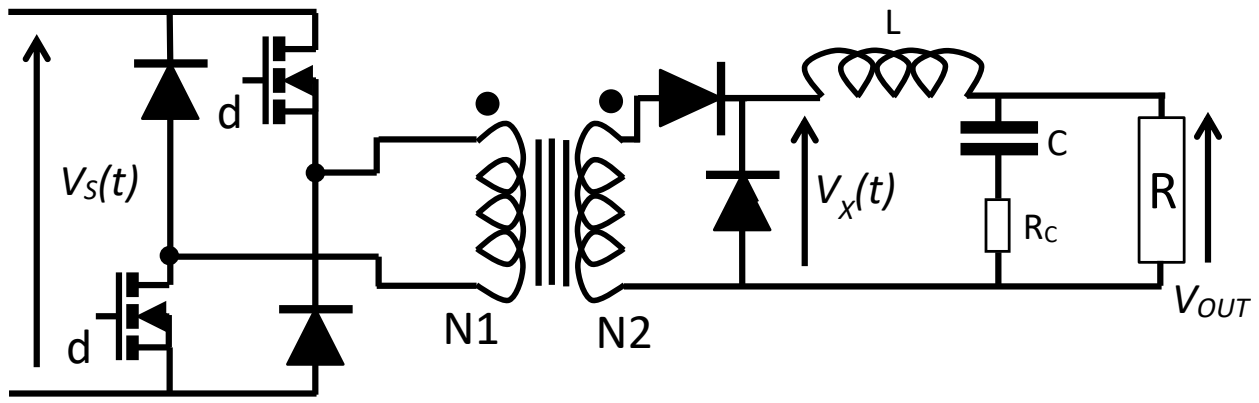
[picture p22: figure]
VOUT

EEEE2046 Electrical Project – Control Design and Control System Modelling | 9

### A.1 Power Circuit Modelling

To model the power circuit, we make some assumptions:

- We model the effect of the rectifier by assuming its output is an ideal voltage source (VS(t)) which has a DC (steady state) value of VSO and a ripple component of vS(t).

VS(t) = VS0 + vS(t)

- We assume all components are ideal – except for the output capacitor where we include the “effective series resistance” – this can have an effect on the control loop. We assume the load is a resistor.

Remember the Forward Converter circuit:

In order to model this for control, we can realise that everything to the left of VX(t) simply acts like a switch to apply the voltage VS(t) (scaled by N2/N1) to the filter and load for a time equal to the duty cycle. We can therefore “forget” about the individual components and model their effect by a single voltage source.

So, we made everything a lot simpler by replacing all the power devices and the transformer by a single pulsed voltage source with variable amplitude (because VS(t) has ripple) and variable duty cycle (because the controller is going to vary the duty cycle to do the control).

However, we still can’t use this model very easily because it is not easy to analyse this circuit when the pulse height and pulse width are time-varying. To get around this problem – we use a “trick”

L

C
V | R VOUT(t) X(t) | RC

### nVS

### (t), n = N2/N1

0

### d(t)T

T
VX
(t) looks like this

EEEE2046 Electrical Project – Control Design and Control System Modelling | 10

that is very commonly used to develop control models of power electronic circuits – the so-called “average model approach”. To do this we use the following fact:

- If the pulse width and pulse amplitude vary at a frequency which is much lower than the switching frequency (1/T), then their effect on the output of the filter can be determined by replacing each pulse with its average value in each switching cycle.

We won’t prove this mathematically (that is for Year 4) – but hopefully you can see that it makes sense intuitively (it is easy to demonstrate with a little PLECS model). In our case the variations in VS(t) and d(t) are mainly at 100Hz and the switching frequency is ≈100kHz – so this is clearly a good assumption.

Now the model becomes:

This is much better because VXLF(t) is now a continuous function (no pulses) – but there is still a problem with this model for control analysis. Since VS(t) and d(t) appear multiplied together, this is model is non-linear. Designing control systems with non-linear models is possible – but it is very difficult and is best avoided if possible (most of the easy to use control design techniques do not work!). To get around this problem we use another “trick” – the so called “linearisation about an operating point”. You will study this in Year 3/4 in more general terms – here we will just look specifically how to use it with the Forward Converter.

To make the system linear we use the idea that we can represent VS(t) as a steady state value plus a time varying value and we do the same for the duty cycle.

VS(t) = VS0 + vS(t)

d(t) = D0 + ∆d(t)

Here D0 is the steady state value of the duty cycle and Δd(t) is the variation in the duty cycle. Now we can write VXLF in terms of these quantities.

VXLF(t) = n(VS0(D0 + ∆d(t)) + D0vS(t) + vS(t)∆d(t))

The “trick” now is to assume that the variations are small compared to the steady state values – so that the last term on the right above is small compared to the other terms and can be neglected. This is a reasonable approximation for many control systems that work around a steady state operating point (like the one we are designing here) – and its use turns what would be an extremely complex design problem into a much simpler one. VXLF(t) can now be written as:

VXLF(t) = n(VS0d(t) + D0vS(t))

L

C
V | R VOUT(t) XLF(t) | RC

### VXLF(t) = nVS

### (t)d(t)

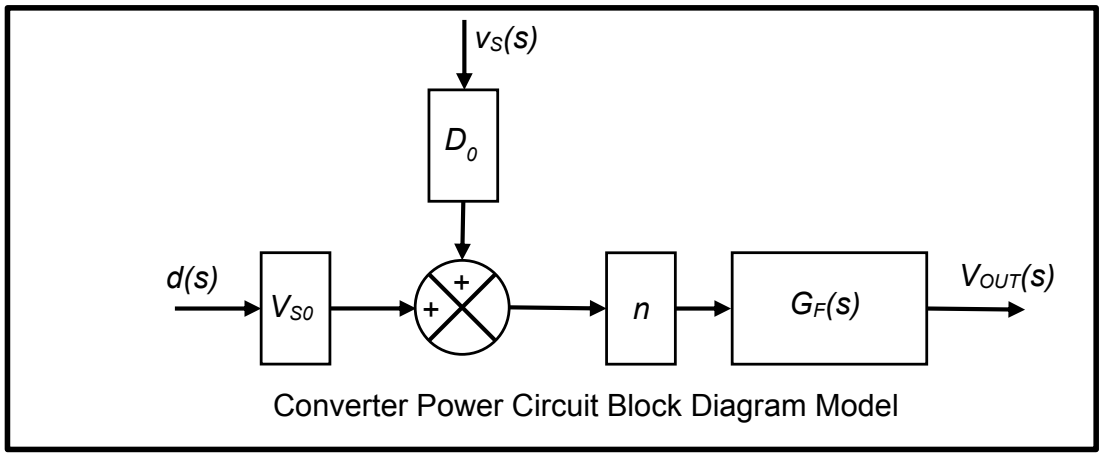
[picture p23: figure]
VOUT(s)

EEEE2046 Electrical Project – Control Design and Control System Modelling | 11

This is now a linear equation that separates the effect of d(t) and vS(t) which is exactly what we need for the control design. The last step is to put it in a block diagram form. Defining the transfer function of the filter as GF(s) (derived later) we can write:

VOUT(s) = GF(s)VXLF(s) = nVS0GF(s)d(s) + nD0GFvS(s)

This gives us the final block diagram model for the power circuit:

Despite the slightly complicated route to get there, this is a simple model that we can use for control design. The model above is what you really need to know to do the design. It is good to understand where it comes from – but it is not essential at this stage if you are struggling with it (you will meet the concepts explained in more detail in Years 3 and 4).

### A.2 PWM Chip Modelling

Fortunately, modelling the PWM chip is quite easy. The relevant section inside the 3424 chip looks like (this is simplified and does not include the output stage etc – but has enough for what we need):

The graph shows how the actual duty cycle (d) will vary with the duty cycle demand (d*). The important part for the control loop is the slope of the line in the active part which defines the “gain” (KPWM) of the PWM generation and is given by:

Converter Power Circuit Block Diagram Model

Comparator

Ramp

VA

VB

duty cycle d

duty cycle demand d*
(voltage input to pin 9) | VA | VB
d*

d

0

dMAX

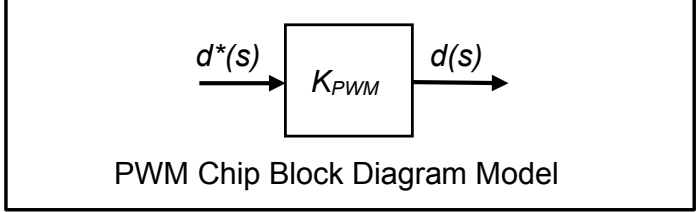
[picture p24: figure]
PWM Chip Block Diagram Model; KPWM

EEEE2046 Electrical Project – Control Design and Control System Modelling | 12

VA and VB can be found from the data sheet and dMAX is typically 45% (0.45).

You may be worried about the “offset” caused by VA (i.e the fact that the duty cycle demand has to reach VA before the any pulses at all are generated). In fact, that has no effect on the control loop analysis because the controller is going to have an integrator – which will automatically
compensate for any offsets. In control block diagram, the PWM chip can simply be represented by:

### A.3 Amplifier (controller) Modelling

The amplifier circuit that you are going to use to implement the controller looks like this (power supplies etc omitted):

VOUT is the output voltage of the converter, the potentiometer allows you to adjust VREF and the potential divider (Rα1, Rα2) allows the output voltage to be scaled down to a suitable value. You will need to think about what a suitable scaling might be – depending on the voltage the op-amps are supplied with, and the value of VREF you decide to set. Z1 and Z2 set the frequency response of the amplifier – they are the main parts that need to be designed (more detail below). You should be able to satisfy yourself that the output of this circuit is related to the input by:

KPWM = dMAX
VB − VA

d*

Rα1

VOUT

Duty cycle demand to UC3524

+

+

VREF

+5V
Rα2

Z1

Z2

VREF; Complete Block Diagram Model; KPWM; VOUT +

EEEE2046 Electrical Project – Control Design and Control System Modelling | 13

d∗(s) = (VREF − αVOUT(s))GC(s) + VREF

GC(s) = Z2(s)
Z1(s)
, | α = | Rα2 Rα1 + Rα2

GC(s) is the transfer function of the amplifier (discussed in more detail later) and α is the potential divider ratio. The first term in the equation for d* is just the error between the scaled output voltage and the reference. The second term is just a DC offset in the amplifier output – it will make no difference to the control loop analysis because the integrator that will form part of GC will compensate for it and we can ignore it (just like we did for the offset in the PWM chip). The amplifier block diagram is therefore:

### A.4 Complete Block Diagram Model

We now have all the individual models and can assemble the complete block diagram below.

This model will enable us to do the control design for GC(s) and it will also enable us to determine the influence of vS(s) (the ripple in the rectifier voltage) on the output voltage for any design of GC(s). It is useful to re-arrange the block diagram to look at these in more detail.

GC(s)

VREF | d*(s)

VOUT(s)

Amplifier Circuit Block Diagram Model

- +

α

EEEE2045). The diagram becomes:; VREF/α; KMISC = αKPWMVS0n; VOUT(s) KMISC

EEEE2046 Electrical Project – Control Design and Control System Modelling | 14

### A.5 Block Diagram Model for Controller design

To design the controller GC(s) (to work out phase margin etc, closed loop gain etc) we just need to consider the main loop and can ignore the vS(s) (i.e. we can set it to zero). Also, it is useful to re-arrange the diagram to get unity gain feedback (using the techniques you have studied in

Here the effect of the potential divider, the PWM chip, the steady state input voltage and the transformer turns ratio have all been combined into one block with a single gain KMISC.

### A.6 Block Diagram Model to determine 100Hz ripple in VOUT

This is a bit more complicated – the final result is the important one. To work out the influence of the ripple in VS on the output voltage VOUT we again consider that VS can be split into 2 parts (a steady state DC part and the ripple part):
VS(t) = VS0 + vS(t)

Now we do the same with the output voltage VOUT:

VOUT(t) = VDC + vO(t)

VDC is just the DC output (10V in your case) while vO(t) is the ripple in the output created by the ripple at the input (vS(t)). We want to know how the % ripple at the output (vO(t)/VDC) is related to the % ripple at the input (vS(t)/VSO) and the control loop design.

The first step to relate the DC values is easy:

VDC = nDOVSO

where DO is the steady state duty cycle. To determine vO(t) in terms of vS(t) we can re-arrange the block diagram and use superposition (i.e. we can ignore VREF in the diagram if we are just interested in the effect of vS(t)). The diagram becomes:

Block Diagram Model for Controller Design

KPWM
αKPWMVS0

EEEE2046 Electrical Project – Control Design and Control System Modelling | 15

Which can be re-arranged into a more familiar form:

Applying what you learnt in EEEE2045 about block diagrams – you should be able to satisfy yourself that vO(s) is related to vS(s) by:

vO(s)

vS(s) = | nDOGF(s)
1 + nαKPWMVSOGF(s)GC(s)

Therefore (using the steady state relationship from before) we can see that:

vO(s)

VDC

= (

vs(s)

VSO

) | GF(s) 1 + nαKPWMVSOGF(s)GC(s)

To work out the effect at 100Hz we need to we need to replace s by jω and evaluate at ω corresponding to 100Hz. That looks a bit complex – but in fact it is quite easy if we realise that the gain of the filter GF at 100Hz is practically unity and that the complicated looking expression in the denominator is just the total loop gain plus 1. Therefore, we can get the very simple result:

Output ripple % at 100Hz = Input ripple at 100Hz/(1 + loop gain at 100Hz)

EEEE2046 Electrical Project – Control Design and Control System Modelling | 16

So, for example, if the input ripple is 10% and we want 1% at the output, then the loop gain at 100Hz will have to be at least 9. When you design your controller – you can use this to work out if it will enable your power supply to meet the ripple specification.

## Appendix B – Transfer Functions

To do the control design, we need to be able to calculate the transfer functions GF(s) and GC(s). These are considered below in detail.

### B.1 Output Filter Transfer Function

To get the transfer function GF(s) = VOUT(s)/VXLF(s), we represent the inductor and capacitor in the Laplace domain and perform a standard circuit analysis (the details are not give here – you should be able to do it) which gives:

GF(s) = ( R
R + RC
) | (1 + sRCC)
(S²LC + S (

L + CRRC

R + RC ) + R
R + RC

)

For any sensible design and operating condition R>>RC and this can therefore be simplified to:

### B.2 Amplifier Transfer Functions

Assuming the control design we assume that the amplifier is one of three types (Type 1, Type 2 or Type 3) depending on the configuration of Z1 and Z2. These are considered in more detail below. The important results for your control implementation are the ones that allow the component values to be calculated.

B.2.1 Type 1 Amplifier

This is just an integrator with the following configurations for Z1 and Z2.

L

1/sC
V | R | VOUT(s) XLF(s) | RC

sL

GF(s) = | (1 + sRCC)
| (S²LC + S ( L R + CRC) + 1)

EEEE2046 Electrical Project – Control Design and Control System Modelling | 17

The transfer function and component values are:

Note that R1 is not unique and has to be chosen first (a sensible choice is needed to make sure the capacitor value is sensible).

B.2.2 Type 2 Amplifier

This has a more complex configuration for Z2 (Z1 is the same as Type 1).

The transfer function is given by:

GC(s) = A
s

(1 + s/ωZ)
(1 + s/ωP)
, | A = | 1 (C1 + C2)R1

, ωZ = 1
C1R2

, ωP = (C1 + C2)
C2C1R2

In order the relate this to the control design method of Venable we need to consider his definitions:

ωC = crossover frequency (the frequency at which the total loop gain is 1)
G = the gain of the amplifier at the crossover frequency
k = Venable’s k-factor which defines the pole and zero frequencies in terms of the crossover frequency ωZ = ωC/k , ωp = kωC (for Type 2).

We can now work out the component values in terms of Venable’s design parameters

Note that R1 is not unique and has to be chosen first (a sensible choice is needed to make sure the other component values are sensible – some iteration may be required).

Z1 | R1 | Z2

C1

GC(s) = A
s

A = 1
C1R1

R2

Z2

C2

C1

C2 = 1

kR1ωCG, C1 = C2(k² − 1), R2 = k ωCC1

, G = Ak
ωC

EEEE2046 Electrical Project – Control Design and Control System Modelling | 18

B.2.3 Type 3 Amplifier

This has a more complex configuration for Z1 (Z2 is the same as Type 2).

The transfer function is given by:

GC(s) = A
s

(1 + s
ωZ1

) (1 + s
ωZ2

)

(1 + s
ωP1

) (1 + s
ωP2

)

A = 1
(C1 + C2)R1

, ωZ1 = 1
C1R2

, ωP2 = (C1 + C2)
C2C1R2

, ωZ2 = 1

C3(R1 + R3) , ωP2 = 1
C3R3

In order the relate this to the control design method of Venable we need to consider his definitions:

ωC = crossover frequency (the frequency at which the total loop gain is 1)
G = the gain of the amplifier at the crossover frequency
k = Venable’s k-factor which defines the pole and zero frequencies in terms of the crossover frequency ωZ = ωC/√k , ωp = √kωC (for Type 3).
Also ωZ2 = ωZ1, ωp2 = ωp1 for Type 3

We can now work out the component values in terms of Venable’s design parameters

Note that R1 is not unique and has to be chosen first (a sensible choice is needed to make sure the other component values are sensible – some iteration may be required).

R2

Z2

C2

Z | C1 1

C3

R1

R3

C2 = | 1
R1ωCG , | C1 = C2(k − 1), | R2 = √k
ωCC1
, | R3 = | R1
(k − 1)
, | C3 = | 1
R3ωC√k

, G = Ak
ωC


EEEE2046 Electrical Project – Control Design and Control System Modelling | 19

## Appendix C – Some useful hints on using MATLAB

Transfer functions can be input directly into Matlab using the ‘tf’ (transfer function) command, with an array which represents the numerator coefficients, and one for the denominator coefficients. For example:

Gp(s) = | (5682) s² + 0.5682s + 5682

The array for the numerator, (5682) is [5682]
The array for the denominator (s²
+0.5682s+5682) is [1 0.5682 5682].

This can be input into Matlab in the command window by typing (note Gp is an arbitrary name):

Gp= tf([5682], [1 0.5682 5682])

Once you have input the transfer function for your system a Bode plot can be plotted simply with the command: bode(Gp);

This gives the response in this case of that in figure 1.

Bode Plot of function plotted in Matlab

There are also various other commands in MATLAB that can be useful for Control including step(Gp) [i.e. the step response], impulse(Gp) [i.e. the impulse response] etc.

Some particularly useful commands for this design exercise are:

margin(Gloop) – this plots a Bode plot and calculates the gain and phase margins if Gloop is the open loop transfer function.

Note that in order to get Gloop – you can multiply transfer functions together in the same way that you would with variables in MATLAB – for example using:

EEEE2046 Electrical Project – Control Design and Control System Modelling | 20

Gloop = Gcontroller*Gplant

at the command line, where Gcontroller and Gplant have both been defined using the tf command.

You can also calculate the closed loop transfer function using something like:

Gclosedloop = Gloop/(1 + Gloop)

at the command line, then you can use the “step” command to get the step response, or you can use the Bode command to get the closed loop Bode plot (to look at the bandwidth for example).

It is a very powerful tool! – experiment!

Other useful information

[1] Al Watson, “Bode Plots in Software”, November 2017
Information on how to plot Bode plots in various software packages including PLECs, MATLAB and LTSpice.
[2] Venable, H. Dean. “The K Factor: A New Mathematical Tool for Stability Analysis and Synthesis.” Proc. Powercon 10. 1983. San Diego, CA. pp. H1−1 to H1−12
Venable’s original paper on the k-factor Method- Note, this is a difficult- the method has been “tweaked” in this handout

All of these references are in the “Extra Resources for Control Design” on the EEEE2046 Moodle site.

Jon Clare and Al Watson, Updated January 2020

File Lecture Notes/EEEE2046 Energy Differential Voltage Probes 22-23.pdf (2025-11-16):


H62PEP EEEE2046 Energy Project– Differential Voltage Probes

## Department of Electrical and Electronic Engineering

## H62PEPEEEE2046: Energy Project: Using Differential Voltage Probes

### 1.0 Introduction

This document considers the use of Differential Voltage probes. You should (will!) use these frequently during the Energy project. The aim of the document is to clarify why they are used when looking at electronic and electrical circuits.

### 2.0 Oscilloscope probes

Figure 1: Standard “Passive” Probe | Figure 2: Differential Voltage Probe

Figure 1 shows a “standard” voltage probe. You will no doubt have used these in various labs during your course. It should be noted that when these are plugged in to the Oscilloscope, the crocodile clip is connect to Earth (ground) of the oscilloscope. This connection is common to all probes that are plugged into the oscilloscope. This can cause difficulties when wanting to probe multiple parts of the circuit which are “floating” or not connected to this commonly shared ground. Under these circumstances, it is much better to use a Differential Voltage Probe.

A Differential Probe is basically a differential amplifier circuit (and in some cases a full instrumentation amplifier)- you may have come across these circuits in your studies of operational amplifiers. The differential probe circuit is very well designed in order to achieve all of the desirable characteristics of a good differential amplifier (wide bandwidth, good noise rejection etc.)- as a result they generally cost a lot more than a passive probe- treat them with care!

Because of their non-passive nature, the internal circuits of a differential probe must be powered. On the probes in the lab (similar to figure 2) you will find a power supply connection on the side- note, there is also an on/off switch…. Make sure your turn the probe on when using it! If powered using batteries- also remember to turn it off when not in use.

These probes are used frequently in the testing and debugging of power electronics circuits. The examples in section 3 should clarify why this is the case.


H62PEP EEEE2046 Energy Project– Differential Voltage Probes

### 5.03.0 Examples of why Differential probes are useful

Figure 2 shows a basic circuit which can easily be used to show one of the common pitfalls when using passive probes in a circuit.

Figure 3: Test circuit for probe example

Measuring a “floating voltage” in a circuit

In figure two there is a 3V voltage source across three series connected resistors (all of a common value, R). By “floating voltage” we mean a voltage which is not referred directly to the 0V part of the circuit (this is a loose definition, but will do for now).

If we take a passive probe and connect the clip to point 1 and the probe tip to point 2, we will see a voltage of 1V on our oscilloscope. Let’s now say that we wanted to take another probe and measure the voltage across the middle resistor, between points 2 and 3. For this, we connect the probe clip to point 2 and the probe tip to point 3. We expect to also see 1V, but instead we 1.5V. Why is this?

Remember, from above, that the clips of the probes are connected together inside the scope and bonded to earth (ground). This means that when we probe the second resistor we have a clip from the first probe connected to point 1 and the clip from the second probe connected to point 2. Since these two clips are connected together inside the scope- this short circuits the bottom resistor, leaving only the middle and top resistors in circuit. Since they have the same resistance, at point 3 we will see half of the input voltage rather than a third of it- i.e. we get a voltage of 1.5V instead of 1V.

A differential probe does not have one of its probes connected directly to earth through the internal circuit of the scope. As a result the two leads effectively “float” and can be connected anywhere in the circuit, without affecting its operation.

Measuring differentially with two passive probes

H62PEP EEEE2046 Energy Project– Differential Voltage Probes

Another way of measuring the voltage across the middle resistor would be to connect one probe between point 1 and 2, and another probe between 1 and 3- note that there is now a common connection between the 2 clips (i.e. they are both connected at 1) and therefore none of the resistors are short circuited. We can now use the Maths functions on the scope to subtract one from the other in order to gain the voltage across the middle resistor. This method works but can result in a lot of noise on the final signal on the Maths channel.

Differential probes are very good at blocking “Common Mode” noise (see your Op-Amp notes and the term “Common Mode Rejection Ratio”). As a result, if it is placed directly across points 2 and 3, accurate, low noise measurements of the voltage across this middle resistor can be taken.

Non-isolated Power Supplies

As you may have learned from you lectures on Power Electronics- not all power supplies have isolation. As a result, some of them will already have a connection of their output voltage to earth. Care must be taken when probing such systems with passive probes as clipping the probe (not the tip, the clip) anywhere above this potential may result in a short circuit through the oscilloscope causing damage.

This is a reason why it is safer to use a differential voltage probe since this is not directly connected to the earth of the oscilloscope. You must, however, always respect the voltage ratings of the probe which are usually clearly printed on the device. You should also make use of the range select switch on the probe to get the most accurate voltage measurement.

### 6.04.0 Uses of differential probes in the Energy Project

In the Energy project, there are many cases where differential voltage probes are useful. These include:
- Looking at the isolated outputs of the gate drive circuit
- Probing the voltage in the main power circuit when a passive probe is making measurements on the non-power (i.e. logic, PWM) circuits
- Looking at the voltage across the output filter inductor
- Looking at the voltage across the two MOSFETs in the forward converter (note they don’t have a common connection)
- Etc. (speak to us in the lab)

As a result, you should get used to using these probes in the lab. Remember, they come with a power supply and must be powered (there is an internal circuit that needs powering).

Confused?

There are two very good videos (amongst others) on YouTube that may help with your understanding of the above. Failing that, speak to the staff in the lab.

https://www.youtube.com/watch?v=OZDijMDHmtI

H62PEP EEEE2046 Energy Project– Differential Voltage Probes https://www.youtube.com/watch?v=a28lVMsWFEY

Al Watson, November 2018

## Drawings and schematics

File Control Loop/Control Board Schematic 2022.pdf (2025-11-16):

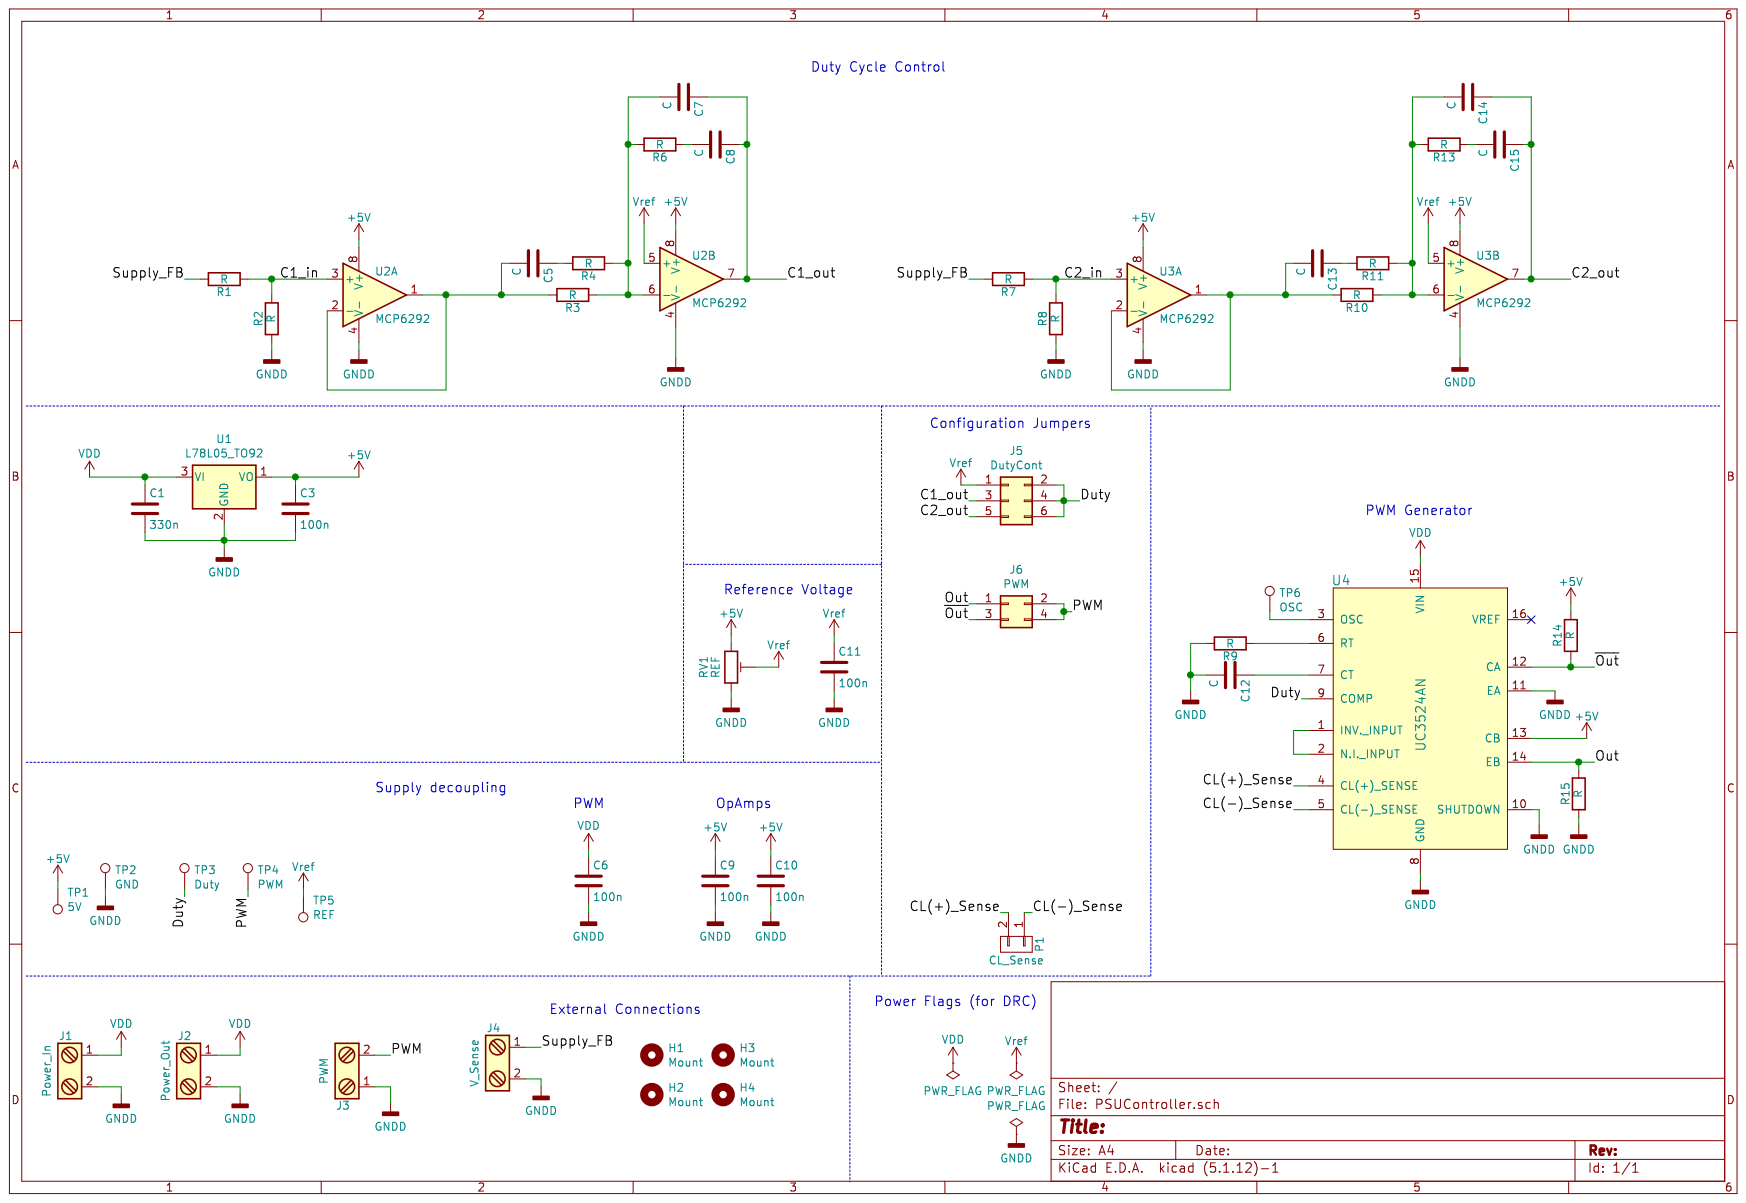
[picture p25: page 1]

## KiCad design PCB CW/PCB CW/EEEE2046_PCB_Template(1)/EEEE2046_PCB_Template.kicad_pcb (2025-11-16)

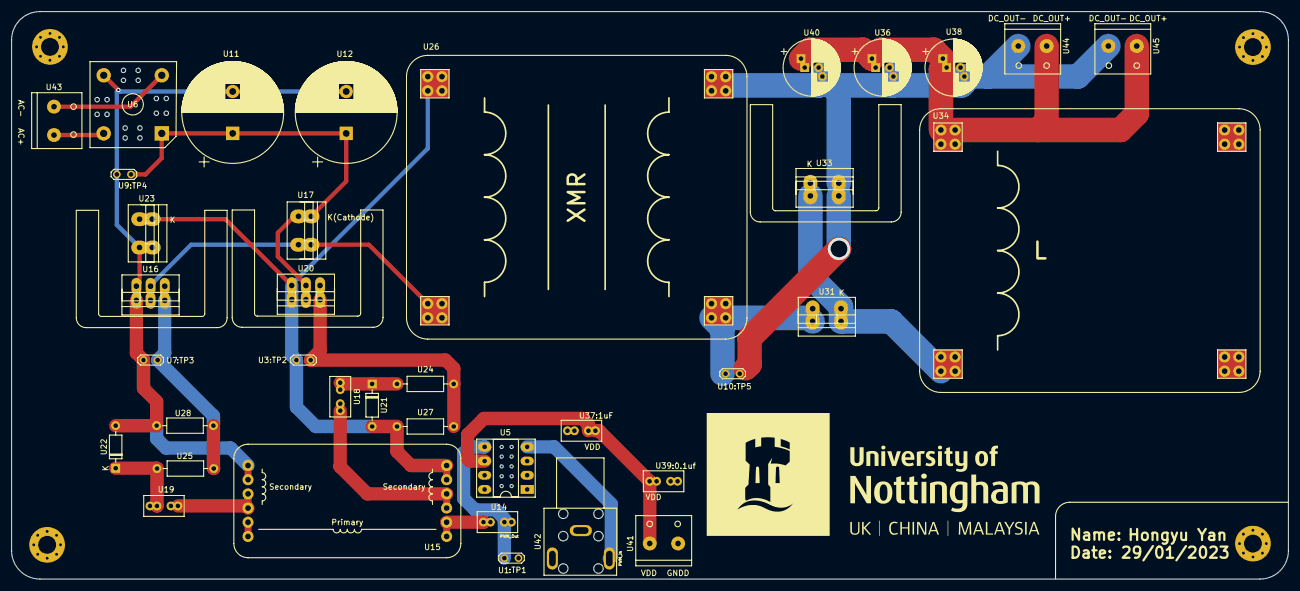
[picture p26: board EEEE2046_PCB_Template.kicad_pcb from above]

Board: 2 copper layers, 228.6 x 101.6 mm, 44 parts (0 on the bottom side), 21 nets.

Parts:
H2, H2#2, H4, H4#2: Mount; MountingHole_3.2mm_M3_Pad_Via
U1: TP_PWM_Out; TestPoint_2Pads_Pitch2.54mm_Drill0.8mm
U2-Mosfet1, U3-Diode1, U4-Diode1: TO220_Heatsink
U3: TP_Q1_Gate; TestPoint_2Pads_Pitch2.54mm_Drill0.8mm
U5: TC4425AVPA; DIP-8_W7.62mm_Socket_LongPads
U6: VS-KBPC606PBF; Diode_Bridge_Vishay_KBPC6
U7: TP_Q2_Gate; TestPoint_2Pads_Pitch2.54mm_Drill0.8mm
U9: TP_DC_Link; TestPoint_2Pads_Pitch2.54mm_Drill0.8mm
U10: TP_Trans_Out; TestPoint_2Pads_Pitch2.54mm_Drill0.8mm
U11, U12: ECA2AM102; CP_Radial_D18.0mm_P7.50mm
U14, U18, U19: F; C_Rect_L7.0mm_W3.5mm_P2.50mm_P5.00mm
U15: Toroid-Transformer_1P_2S
U16, U20: IRFI530NPbF; TO-220FPAB
U17, U23, U31, U33: BYV25FX-600; SOD113
U21, U22: V; D_DO-35_SOD27_P7.62mm_Horizontal
U24, U25, U27, U28: R; R_Axial_DIN0207_L6.3mm_D2.5mm_P10.16mm_Horizontal
U26: ETD_34-Transformer_1P_1S; ETD_34-XMR
U34: H; ETD_34-L
U36, U38, U40: F; CP_Radial_D10.0mm_P2.50mm_P5.00mm
U37: 1uF; C_Rect_L7.0mm_W3.5mm_P2.50mm_P5.00mm
U39: 0.1 uF; C_Rect_L7.0mm_W3.5mm_P2.50mm_P5.00mm
U41: PWM_Power; 2wayTerminalBlock
U42: PWM_Input; LP-0841-3B-05A
U43: AC_Power; 2wayTerminalBlock
U44, U45: Converter_Out; 2wayTerminalBlock

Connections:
/Converter_Out(+): U34.1, U36.1, U38.1, U40.1, U44.1, U45.1
/Converter_Out(-): U10.2, U26.3 (SA), U33.2 (A), U36.2, U38.2, U40.2, U44.2, U45.2
/PWM_COM_A: U3.2, U15.4 (SB), U20.3 (S), U21.2 (A), U23.1 (K), U26.1 (AA), U27.1
/PWM_COM_B: U6.3 (-), U7.2, U9.2, U11.2, U12.2, U15.6 (SD), U16.3 (S), U22.2 (A), U23.2 (A), U28.1
/PWM_Input: U5.4 (IN_B), U42.2
/PWM_OUT_A: U3.1, U20.1 (G), U24.1, U27.2
/PWM_OUT_B: U7.1, U16.1 (G), U25.1, U28.2
/PWM_Out: U1.1, U5.5 (OUT_B), U14.2
/Rectifier_DC(+): U6.1 (+), U9.1, U11.1, U12.1, U17.1 (K), U20.2 (D)
/Transformer_Out(+): U10.1, U26.4 (SB), U31.2 (A)
/VAC(+): U6.4, U43.2
/VAC(-): U6.2, U43.1
GNDD: U1.2, U5.3 (GND), U15.2 (AB), U37.2, U39.2, U41.2, U42.1
unnamed: U14.1, U15.1 (AA)
unnamed: U15.3 (SA), U18.2
unnamed: U15.5 (SC), U19.2
unnamed: U16.2 (D), U17.2 (A), U26.2 (AB)
unnamed: U18.1, U21.1 (K), U24.2
unnamed: U19.1, U22.1 (K), U25.2
unnamed: U31.1 (K), U33.1 (K), U34.2
VDD: U5.6 (VDD), U37.1, U39.1, U41.1

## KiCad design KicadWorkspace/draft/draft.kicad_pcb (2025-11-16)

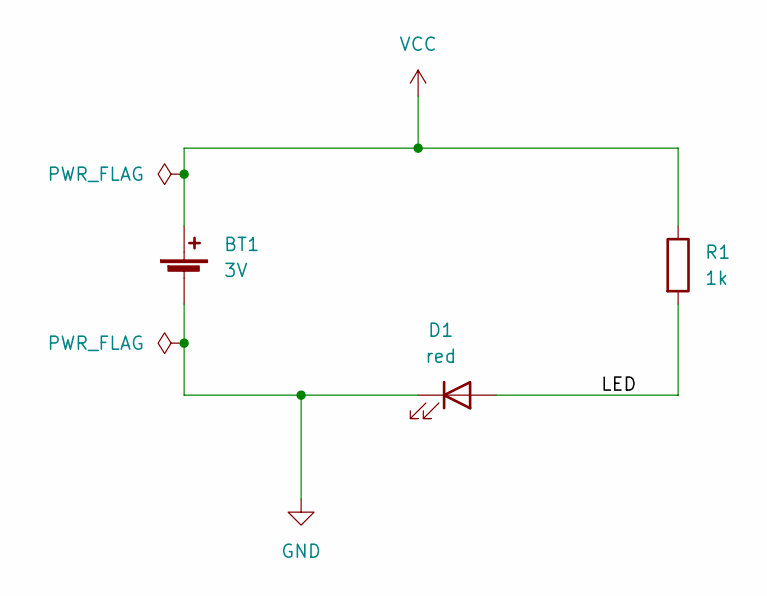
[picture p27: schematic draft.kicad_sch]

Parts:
BT1: 3V; Battery_Panasonic_CR1632-V1AN_Vertical_CircularHoles
D1: red; LED_D3.0mm
R1: 1k; R_Axial_DIN0309_L9.0mm_D3.2mm_P12.70mm_Horizontal

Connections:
/LED: D1.2 (A), R1.2
GND: BT1.2 (-), D1.1 (K)
VCC: BT1.1 (+), R1.1

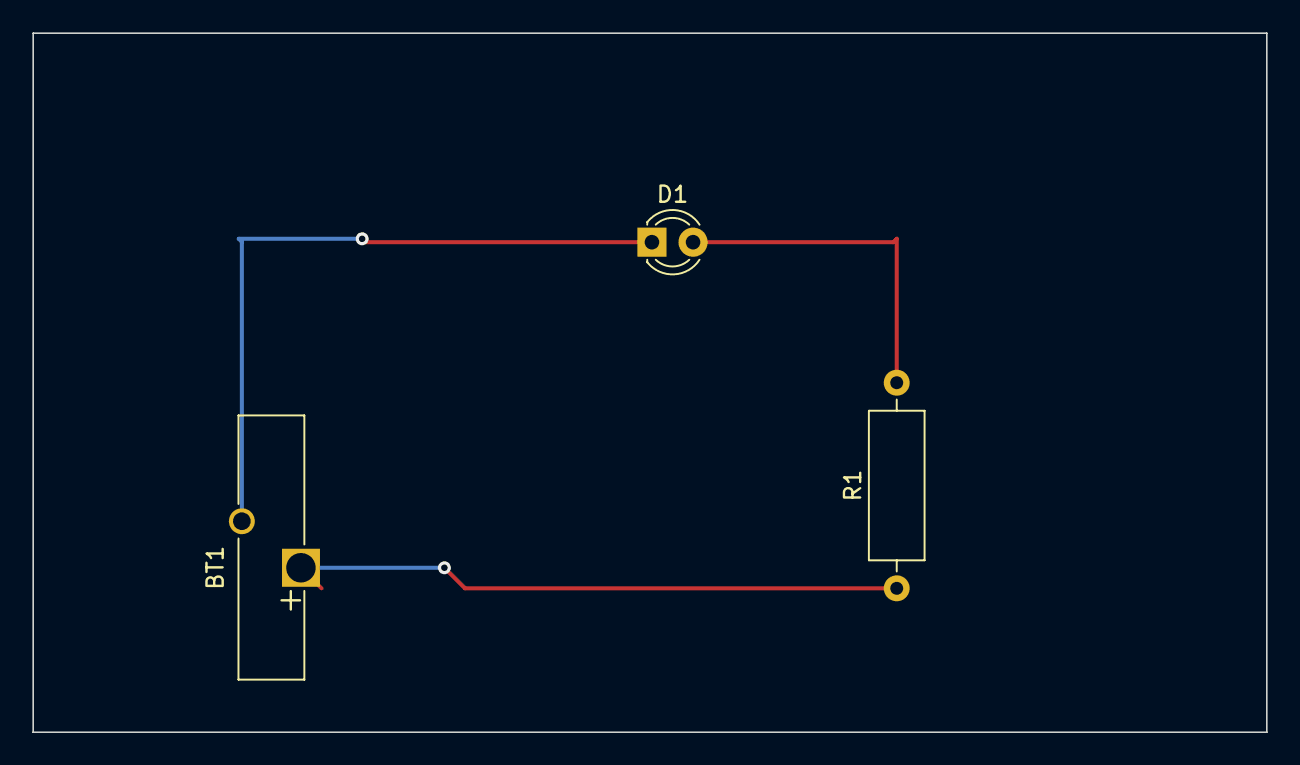
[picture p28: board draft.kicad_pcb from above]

Board: 2 copper layers, 76.2 x 43.2 mm, 3 parts (0 on the bottom side), 3 nets.
